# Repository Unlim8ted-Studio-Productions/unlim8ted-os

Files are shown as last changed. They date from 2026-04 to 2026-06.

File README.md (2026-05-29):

<div align="center">
<h1>Unlim8ted Phone</h1><p>A custom CM4-based handheld phone project</p>

<br>





<table>
<tr>

<td width="50%">
  <a href="https://raw.githubusercontent.com/Unlim8ted-Studio-Productions/unlim8ted-phone/refs/heads/main/docs/assets/render.mkv">
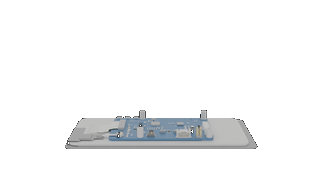
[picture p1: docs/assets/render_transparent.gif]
  
</a>
</td>

<td width="50%">
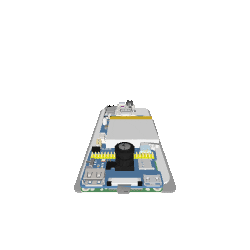
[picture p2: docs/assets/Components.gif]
  
</td>

</tr>
</table>

</div>

---

<h2>Overview</h2>

<p>
Unlim8ted Phone is a handheld phone project built around the Raspberry Pi Compute Module 4.
</p>

<p>
This repository contains the hardware, enclosure design, operating system work, and archived PCB development files for the project.
</p>

---

<h2>Repository Layout</h2>

```text
/
├─ 3d/        enclosure, renders, printable parts
├─ docs/      project documentation
├─ os/        Unlim8ted OS source and docs
├─ pcb/       archived PCB design files
└─ README.md
```

---

<h2>Hardware + Cost Breakdown</h2>

<table>

<tr>
<th align="left">Component</th>
<th align="left">Details</th>
<th align="right">Price</th>
</tr>

<tr>
<td>Compute Module</td>
<td>Raspberry Pi CM4 Lite — 8GB RAM</td>
<td align="right">$105.00</td>
</tr>

<tr>
<td>Carrier Board</td>
<td>Waveshare CM4-NANO-C</td>
<td align="right">$29.99</td>
</tr>

<tr>
<td>Display</td>
<td>Waveshare 6.25-inch DSI LCD</td>
<td align="right">$59.99</td>
</tr>

<tr>
<td>Storage</td>
<td>32GB microSD card</td>
<td align="right">$20.00</td>
</tr>

<tr>
<td>Power Board</td>
<td>Seeed LiPo Rider Plus</td>
<td align="right">$4.90</td>
</tr>

<tr>
<td>Battery</td>
<td>3.7V 3000mAh LiPo</td>
<td align="right">$12.49</td>
</tr>

<tr>
<td>Display Cable</td>
<td>15cm double-sided 15-pin DSI cable</td>
<td align="right">Included</td>
</tr>

<tr>
<td>USB Cable</td>
<td>Adafruit USB Type A → USB Type C</td>
<td align="right">$2.95</td>
</tr>

</table>

<br>

<div align="center">

<h1>$235.32</h1>

<sub>Current estimated build total</sub>

</div>

---

<h2>PCB Status</h2>

<p>
The PCB files inside <code>/pcb</code> are archived only.
</p>

<p>
The original custom PCB revision was abandoned in favor of already-manufactured off-the-shelf boards.
</p>

<p>
These files are preserved strictly for reference purposes and should not be used for fabrication or assembly.
</p>

---

<h2>Project Links</h2>

<div align="center">

<a href="./docs/">Documentation</a>

<br><br>

<a href="./os/">OS Source</a>

<br><br>

<a href="./3d/">3D Files</a>

<br><br>

<a href="./pcb/">Archived PCB Files</a>

</div>

---

<div align="center">

<h3>Unlim8ted Studios</h3>

<p>
Hardware • Embedded Systems • OS Development • Industrial Design
</p>

</div>

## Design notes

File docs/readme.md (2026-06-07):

# Unlim8ted Phone Docs

This folder documents the Unlim8ted Phone repository as it exists today: the CM4 software stack, enclosure assets, hardware baseline, and archived board work.

## What is in this repo

- A Raspberry Pi CM4 kiosk-style phone shell and backend under `os/`
- Printable enclosure exports and supporting 3D assets under `3d/`
- Archived custom PCB work under `pcb/`
- Project-level notes in this `docs/` folder

## Start here

- [Repository Map](repo-map.md)
- [OS Architecture](os-architecture.md)
- [Hardware And Design Notes](hardware-and-design.md)

## Current direction

The project is currently built around off-the-shelf CM4 hardware, a custom enclosure, and a custom kiosk-style software stack.

The `pcb/` tree remains useful reference material, but it is no longer the active hardware path.

## Important repo realities

- The main software entrypoint is `os/build.sh`, which now only handles the deferred CM4 flash-and-first-boot flow rather than acting as a general image builder.
- The device UI is a local web app served by a Python backend on port `8080`.
- The app set is mostly local-first and stateful, with several apps backed by JSON files under the runtime state directory.
- Some Blender source may live outside the pushed repository; the tracked tree primarily preserves exports and reference assets.

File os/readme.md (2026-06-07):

# Unlim8ted OS

This directory now builds Unlim8ted OS by customizing official upstream Linux images instead of compiling a full Buildroot system from source.

## Structure

- `overlay/` holds the files copied into the target image, including `/etc`, `/opt`, and the Raspberry Pi boot configuration tracked in this repo.
- `build.sh` is the main build entrypoint for the deferred CM4 provisioning flow.
- `reapply-overlay.sh` reapplies the current overlay to an existing CM4 card without reflashing the base image.
- `build/` receives the finished artifacts after each build.

## Base Images

- CM4 now defaults to the official Raspberry Pi OS Lite 64-bit image `2026-04-21-raspios-trixie-arm64-lite.img.xz`. This is the April 21, 2026 Raspberry Pi OS Lite release for Raspberry Pi 4 / CM4 class hardware.
- `x86_64` uses the official Debian 12 amd64 generic cloud image. That keeps Chromium available as a normal apt package and is straightforward to boot under QEMU or other desktop virtualization.

## Included software

Both targets install kiosk-oriented packages with `apt`, then apply the repo overlay:

- `systemd` from the base image
- `python3`
- `Chromium`
- Bluetooth support
- Wi-Fi support
- Xorg and `xinit`
- `openbox`

The overlay still provides the kiosk startup path:

- `etc/systemd/system/getty@tty1.service.d/autologin.conf` skips the tty1 login prompt.
- `etc/systemd/system/unlim8ted.service` starts X with `xinit`.
- `opt/unlim8ted/bin/kiosk-session.sh` starts the backend, and the backend launches Chromium in app mode.

## Requirements

Run `build.sh` from a Linux shell, including WSL.

Required host tools:

- `sudo`
- `curl`
- `losetup`
- `mount`
- `parted`
- `resize2fs`
- `e2fsck`
- `rsync`
- `unzip`
- `xz-utils`

Additional requirement for CM4 DSI1 boot overlay generation:

- `p7zip-full`
- `device-tree-compiler`

Additional requirement when building the default CM4 image on an `x86_64` host:

- `qemu-arm-static`

The build script flashes the base image, resizes partitions, applies the overlay, seeds first-boot settings, and enables the first-boot installer.

## CM4 Card Layout

Default Unlim8ted card partitions:

- `3 - storage ext4` is the user storage partition for files, downloads, pictures, videos, music, and captures.
- `2 - rootfs ext4` is the OS filesystem with `/opt/unlim8ted`.
- `1 - bootfs FAT` is the Raspberry Pi boot partition.

The boot files must be on the real FAT `bootfs` partition. An empty `rootfs\boot\firmware` directory is normal when `bootfs` is not mounted there.

For the Waveshare DSI1 + double-camera CM4 setup, `build.sh` can optionally install `dt-blob.bin` into `bootfs`. By default it builds that file from Waveshare's `dt-blob-disp1-double_cam.dts`, which can affect camera and HDMI behavior. The build script does not copy `.dts` files into `bootfs`; set `UNLIM8TED_CM4_DSI1_DT_BLOB=1` to enable `dt-blob.bin` generation, or place a prebuilt `overlay/boot/dt-blob.bin` in the repo to override the generated path.

The tracked boot overlay also forces `dtoverlay=dwc2,dr_mode=host` so USB input devices enumerate in host mode during CM4 testing.

## Build Script

Common commands:

```sh
# Show disks before selecting a target.
bash os/build.sh list-devices

# Deferred CM4 build: flash the pinned stock OS, resize rootfs, apply overlay, install packages on first boot.
bash os/build.sh deferred --device /dev/sdi

# Override the deferred CM4 rootfs target size.
bash os/build.sh deferred --device /dev/sdi --root-size-mib 9728

# Seed first-boot Wi-Fi credentials during a deferred build.
bash os/build.sh deferred --device /dev/sdi --wifi-ssid "MyWiFi" --wifi-password "secret" --wifi-country US

# Reapply the current overlay to an already-flashed CM4 card.
sh os/reapply-overlay.sh /dev/sdi
```

Deferred CM4 builds flash the pinned stock Raspberry Pi OS Lite image directly to the selected device, expand `rootfs` to 10GiB by default, create `LABEL=storage` from the remaining space, apply the overlay, and skip host-side package installation. If the build is running interactively, the script asks for the Wi-Fi country first, defaulting to `US`, then optionally asks for an SSID/password and writes those settings into the first-boot environment file.

On first boot:

- the image autologins root on `tty1`
- `firstboot-install.sh` waits indefinitely for network input if needed
- package installation runs on the CM4
- on success, `unlim8ted.service` starts the kiosk
- on failure, the script drops into an interactive recovery shell on `tty1`

If you land in the recovery shell and the system is otherwise ready, you may only need to type `reboot`.

Default credentials seeded into the image:

- username: `unlim8ted`
- password: `unlim8ted`

The `storage` partition is mounted at `/home/unlim8ted` and is used for user files, downloads, pictures, videos, music, and captures.

Optional environment variables:

- `UNLIM8TED_WORK_DIR=...` sets the build work/cache directory.
- `UNLIM8TED_BASE_IMAGE_DIR=...` sets the base image cache directory.
- `UNLIM8TED_CM4_PACKAGES=...` overrides the apt package list for CM4.
- `UNLIM8TED_DEFAULT_USER=...` overrides the seeded default username.
- `UNLIM8TED_DEFAULT_PASSWORD=...` overrides the seeded default password.

## Notes

- The build is now much faster than a full Buildroot desktop stack because it reuses prebuilt distro packages.
- You still keep the repo-managed overlay and boot config.

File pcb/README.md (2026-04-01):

# PCB Folder

This folder contains outdated and unfinished PCB design work, archived revisions, fabrication output, supporting libraries, and reference material for the phone project. None of the custom PCB files should be fabricated, and ignoring this warning could result in damage.

## Layout

- `custom pcb files/`
  - the KiCad project folders and board files
  - currently includes `phone/`, `phone-part-1/`, and `phone6layer/`
- `libraries/`
  - custom symbol and footprint libraries
  - vendor library imports used by the projects
- `models/`
  - component, enclosure, and vendor-supplied 3D assets
- `fabrication/`
  - gerbers, pick-and-place files, plots, and JLCPCB exports
- `references/`
  - datasheets, diagrams, screenshots, and video captures
- `scripts/`
  - helper scripts used alongside the PCB workflow
- `archives/`
  - backups, candidate revisions, zip bundles, and superseded files

## Working Projects

- `custom pcb files/phone/`
  - main phone schematic project and its exported 3D artifacts
- `custom pcb files/phone6layer/`
  - 6-layer phone board revision
- `custom pcb files/phone-part-1/`
  - partial board split-out

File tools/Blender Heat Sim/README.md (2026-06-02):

# CAD Heat Sim Blender Add-on

Install the `Blender Heat Sim` folder as a Blender add-on zip or copy it into your Blender add-ons directory.

What it does:
- Adds a `Heat Sim` tab to the 3D View sidebar.
- Lets you assign thermal material presets or custom thermal properties per object.
- Simulates transient heating with internal power, fixed-temperature boundaries, object-to-object contact conduction, convection, and radiation.
- Supports component presets with idle-to-max power scaling driven by a scene-wide load control.
- Colors the model by temperature and exports summary CSV data.
- Includes improved preview controls for current-frame contrast, hottest/coolest part readout, and one-click viewport setup.
- Uses a two-node core/surface thermal model per object for better internal-vs-external temperature behavior.
- Uses adaptive predictor-corrector time integration and face-aware contact estimation for higher numerical and geometric fidelity.
- Supports a free `SfePy` server backend that voxelizes the Blender scene and solves a transient thermal FEM case in an external Python environment.

Included presets:
- Metals and structural materials such as aluminum, copper, stainless steel, titanium, glass, silicon, graphite pad, and PCB FR4.
- Printed and enclosure materials such as ABS, PLA, polycarbonate, TPU, and nylon.
- Electronics-oriented presets such as `LiPo Battery`, `CM4 PCB`, `CM4 SoC Package`, `CM4 Module`, and `Waveshare 6.25 DSI Display`.
- Assembly and interface materials such as `Steel Screw`, `Brass`, `Ceramic`, `Thermal Pad`, `Thermal Paste`, `FPC Ribbon Cable`, and `Adhesive Tape`.
- Device presets for `Raspberry Pi CM4 Lite 8GB`, `Waveshare CM4-NANO-C`, `Waveshare 6.25-inch DSI LCD`, `32GB microSD Card`, `Seeed LiPo Rider Plus`, `3.7V 3000mAh LiPo`, `15cm 15-pin DSI Cable`, and `USB Type A to Type C Cable`.

Recommended workflow:
1. Import or model your CAD parts as separate mesh objects with real-world scale in meters.
2. Select an object, choose a component preset when appropriate, and sync it to copy material and power defaults.
3. Set the scene `System Load` slider to represent idle through maximum sustained use.
4. Use load profiles for active components such as compute modules, displays, chargers, and batteries, or manual heat generation for custom parts.
5. Select objects and apply material or component presets to the rest of the assembly as needed.
6. Mark heatsinks, cold plates, or environment-controlled parts as fixed-temperature boundaries when needed.
7. Run the simulation and inspect the final frame or scrub the preview frame slider.

SfePy workflow:
1. In add-on preferences, set `Server Python` to a normal Python installation outside Blender.
2. Use `Install Server Modules` to install `numpy`, `scipy`, `sfepy`, `trimesh`, and `numpy-stl` into that external Python environment.
3. Use `Start Solver Server` once, or keep `Auto Start Server` enabled.
4. In the Heat Sim panel, switch `Backend` to `SfePy Server`.
5. Set `SfePy Cell Size` small enough for the geometry detail you care about.
6. Use `Export SfePy Case` to generate the voxel mesh and solver files, or `Run SfePy Server Solve` to solve through the server.
7. The add-on writes the generated case, compressed voxel mesh data, Python runner, and server log into the configured case folder.

Mesh viewer:
- Use `tools/Blender Heat Sim/mesh_viewer.py` to inspect generated `.mesh` files outside Blender.
- Example:
```powershell
python "O:\unlim8ted-phone\tools\Blender Heat Sim\mesh_viewer.py" "O:\unlim8ted-phone\3d\heat_sim_cases\heat_sim_full_sfepy\heat_sim_full.mesh"
```
- If no path is provided, the viewer opens a file picker.

Preview tips:
- Use `Set Preview View` to switch Blender to a heat-map friendly material preview automatically.
- Use `Color Scope = Whole Run` to compare temperatures across the entire simulation.
- Use `Color Scope = Current Frame` for stronger contrast at the selected preview time.
- Use `Color Scope = Manual` when you want a fixed engineering temperature scale.
- Use `Preview Temp = Surface`, `Core`, or `Max` depending on whether you want touch temperature, internal hotspot temperature, or the worst-case of both.
- Read the `Hot` and `Cool` labels in the preview panel to see the extreme parts at the current frame quickly.

Accuracy notes:
- Keep geometry to real-world scale in meters.
- Lower `Max Temp Step` for higher temporal accuracy at the cost of longer solve time.
- Lower `SfePy Cell Size` for higher spatial fidelity in the SfePy backend.
- Use separate objects for heat sources, boards, pads, shields, batteries, and displays instead of one merged assembly.
- Use manual thickness overrides on thin stacked parts when the automatic estimate is too coarse.

Notes:
- This is a materially aware lumped thermal network solver inside Blender. It is useful for design iteration, comparison, and finding hot spots.
- It is not a substitute for full finite-element thermal analysis when you need certification-grade accuracy or detailed internal gradients inside a single part.

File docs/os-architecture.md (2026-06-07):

# OS Architecture

## Overview

Unlim8ted OS in this repository is an image-customization workflow rather than a full distribution source tree. It starts from upstream base images, installs the required packages, applies the repo overlay, and enables the kiosk runtime.

There is one supported target:

- `cm4`: Raspberry Pi OS Lite 64-bit based image for the device

## Boot and runtime flow

At runtime the system follows this boot chain:

1. `unlim8ted.service` starts `xinit` on `tty1`
2. `kiosk-session.sh` disables screen blanking, starts Openbox, and launches the backend
3. `backend/main.py` starts a local HTTP server on port `8080`
4. The same Python process launches Chromium in app/kiosk mode pointed at `http://localhost:8080`
5. Chromium loads `ui/index.html` and `ui/app.js`
6. The shell opens apps by calling backend routes, which dispatch into `apps/<app>/main.py`

## Backend responsibilities

`os/overlay/opt/unlim8ted/backend/main.py` is the main runtime process. It is responsible for:

- Serving the shell HTML and JavaScript
- Serving app templates and client scripts
- Routing app API requests
- Sleep, wake, brightness, reboot, shutdown, and kiosk-exit actions
- Wi-Fi and Bluetooth toggles
- Companion pairing/session endpoints
- Media file serving for captures
- Chromium launch

## Runtime services

`os/overlay/opt/unlim8ted/backend/runtime.py` provides the local service layer used by apps.

Key services:

- `StateStore`: JSON-backed persistence under the runtime state directory
- `ContactsService`: default/favorite contacts
- `CommunicationsService`: calls, threads, and messages
- `AccountsService`: owner and mail account state
- `MediaService`: captures and music queue state
- `FilesService`: sandboxed access to allowed filesystem roots
- `NotificationsService`: badge counts and notification state
- `CompanionService`: pairing codes, sessions, device list, and push token metadata
- `AppRegistry`: app discovery and dynamic loading from `apps/*/main.py`

## UI shell

The shell is a mobile-style single-page interface implemented in `ui/index.html` and `ui/app.js`.

Key shell behavior visible in the current implementation:

- Lock screen and home screen flow
- Control center and quick toggles
- Sleep/wake behavior with idle timeout
- App switcher
- Soft keyboard with suggestions and glide typing
- Home screen page swiping and icon rearrangement
- Lightweight performance mode detection for ARM/Linux targets
- Error isolation so a failed app does not kill the shell

## App model

Apps are local modules under `os/overlay/opt/unlim8ted/apps/<app-id>/`.

Common parts:

- `main.py`: manifest plus server-side payload/action logic
- `index.html`: optional app template
- `client.js`: optional rich client behavior

The backend loads app manifests dynamically. Some apps return structured payloads for generic rendering, while others ship dedicated templates and client-side behavior.

## Data and storage

Default runtime paths are configured in `overlay/etc/default/unlim8ted`:

- state: `/var/lib/unlim8ted`
- user storage: `/home/unlim8ted`
- user files: `/home/unlim8ted/Files`
- captures: `/home/unlim8ted/Pictures/Captures`
- Chromium profile: `/var/lib/unlim8ted/chromium-profile`

The CM4 image layout also reserves a separate `storage` partition mounted at `/home/unlim8ted`.

## Build workflow summary

`os/build.sh` now supports one provisioning flow only:

- flash the pinned Raspberry Pi OS Lite base image to an SD or USB device
- resize the root partition to a fixed size
- create a `storage` partition for `/home/unlim8ted`
- apply the tracked overlay
- suppress Raspberry Pi OS first-run setup
- boot into `tty1` root autologin
- run `firstboot-install.sh` on the device after network is available

The deferred first-boot script installs packages on the target device instead of preinstalling them during image creation.

Current first-boot behavior:

- `tty1` autologins root
- `firstboot-install.sh` prompts for network access if needed and waits indefinitely
- on failure, the script opens an interactive recovery shell on `tty1`
- if the system is otherwise ready, a simple `reboot` may be enough to continue cleanly on the next boot

The image also seeds a default local user for Raspberry Pi OS first-run setup suppression:

- username: `unlim8ted`
- password: `unlim8ted`

## Practical caveats

- The build script must run from Linux or WSL, not native Windows.
- Several apps are intentionally local-state implementations rather than fully integrated phone services.
- Package installation now happens on first boot, so network availability on the device is part of provisioning.

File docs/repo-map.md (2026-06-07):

# Repository Map

## Top level

- `README.md`: project overview and current hardware cost summary
- `docs/`: repo documentation
- `os/`: Unlim8ted OS image builder, overlay, backend, UI, and bundled apps
- `3d/`: enclosure exports, renders, and model assets
- `pcb/`: archived KiCad projects, fabrication output, vendor libraries, and references

## `os/`

This is the active software side of the project.

- `build.sh`: single-purpose CM4 deferred flasher that writes the base image, applies the overlay, and leaves package installation to first boot on the device
- `overlay/boot/config.txt`: tracked Raspberry Pi boot configuration for the Waveshare DSI panel and camera setup
- `overlay/etc/default/unlim8ted`: runtime environment variables for display, storage, captures, and Chromium profile paths
- `overlay/etc/systemd/system/unlim8ted.service`: kiosk systemd service that launches `xinit`
- `overlay/opt/unlim8ted/bin/kiosk-session.sh`: starts Openbox and then the Python backend
- `overlay/opt/unlim8ted/backend/`: Python backend and runtime services
- `overlay/opt/unlim8ted/ui/`: phone shell HTML and JavaScript
- `overlay/opt/unlim8ted/apps/`: per-app templates, Python logic, and optional client scripts
- `overlay/opt/unlim8ted/commands/registry.json`: command surface exposed to the shell and companion-facing clients

## `os/overlay/opt/unlim8ted/apps/`

Current app folders discovered from the repo:

- `browser`: local tab state and embedded browser shell
- `camera`: camera actions and capture flow
- `clock`: alarms, timers, and world clock state
- `code`: text/code editor over the user files area
- `files`: file browser, preview, editing, rename, and delete operations
- `gallery`: capture browser
- `mail`: local mailbox and draft state
- `maps`: placeholder destination/search state
- `messages`: local conversation state plus companion sync support
- `music`: local queue and playback state
- `notes`: local notes state
- `phone`: favorites, dial, contacts, and recents
- `settings`: account, system, notification, and connectivity summary
- `store`: installed app list and command surface view
- `terminal`: terminal app frontend/backend

Several of these apps are local-first modules backed by JSON state rather than external service integrations.

## `3d/`

This tree contains printable and presentation assets for the enclosure side of the project.

- Exported printable parts such as `Back_Cover.stl`, `Bottom_Cover.stl`, `Battery_Holder.stl`, and `Main_Case.stl`
- Render outputs such as `render.gif`, `render.mkv`, and `Components.gif`
- Mixed source/reference assets including `.glb` and `.stl` files.

## `pcb/`

This tree is archived.

- `custom pcb files/`: primary KiCad project folders and board revisions
- `libraries/`: imported or custom footprints/symbols
- `models/`: vendor and reference 3D assets
- `fabrication/`: gerbers and fabrication exports
- `references/`: screenshots, diagrams, schematics, datasheets, and videos
- `scripts/`: helper tooling such as the KiCad-to-OpenSCAD case generator
- `archives/`: backups, candidate layouts, zips, and superseded revisions

## `docs/assets`

Various renders used in the documentation.

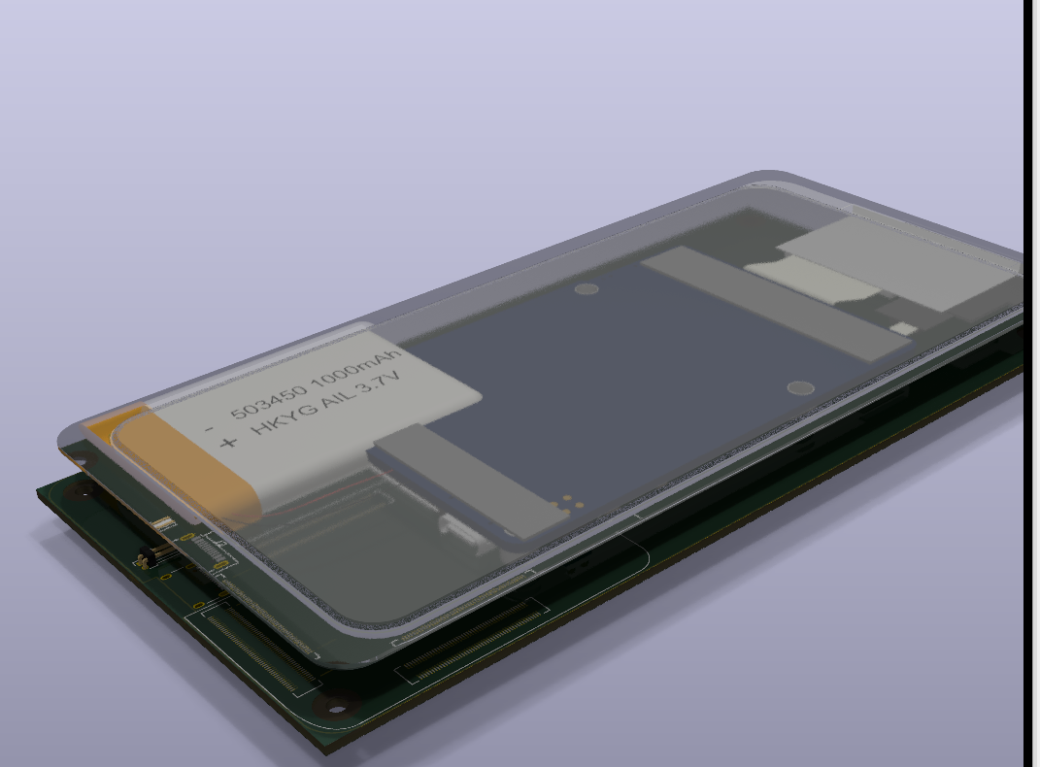
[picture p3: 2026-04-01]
pcb/references/images/Screenshot 2025-11-21 183611.png

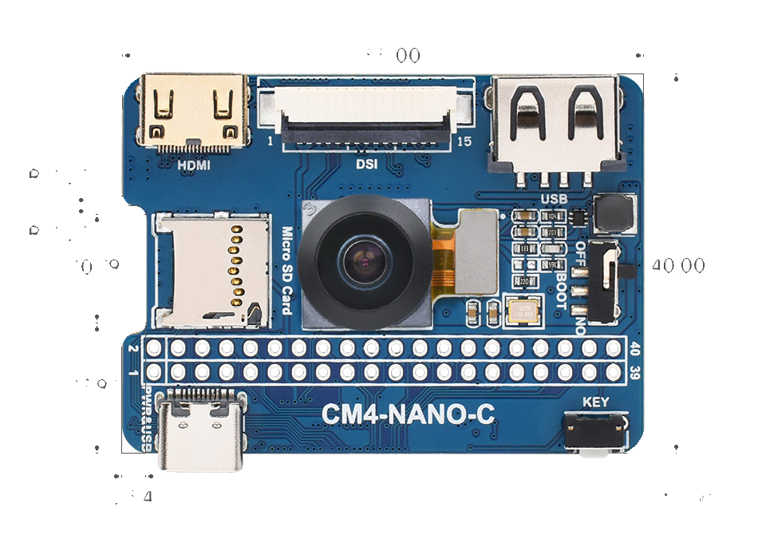
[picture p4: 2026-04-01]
pcb/references/images/PineTools.com_CM4-NANO-C02.png

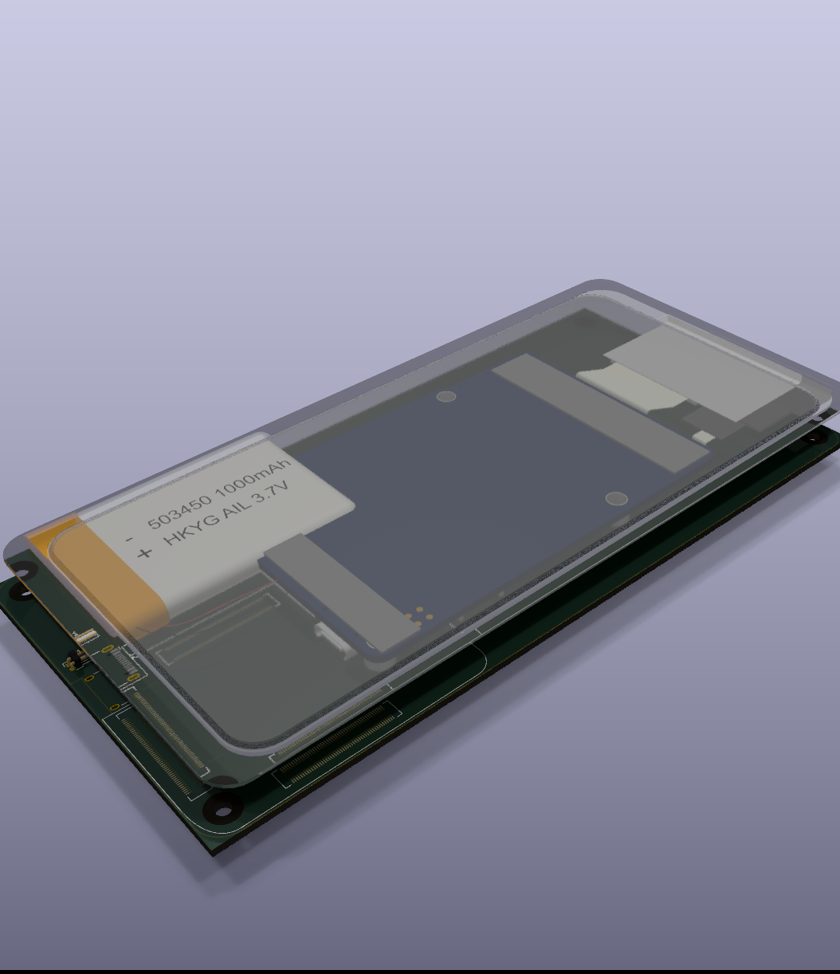
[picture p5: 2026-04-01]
pcb/references/images/Screenshot 2025-11-21 183740.png

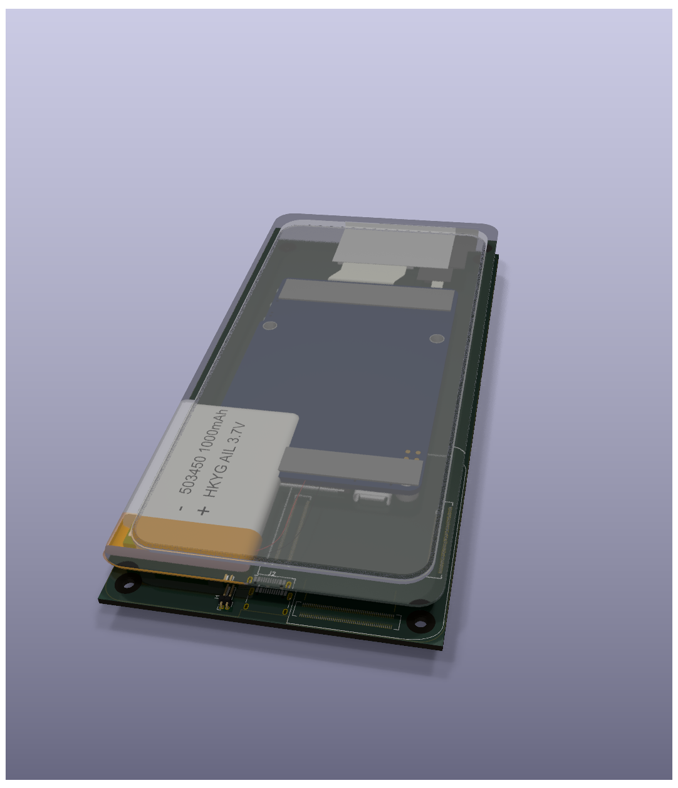
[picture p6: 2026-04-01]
pcb/references/images/Phone.png

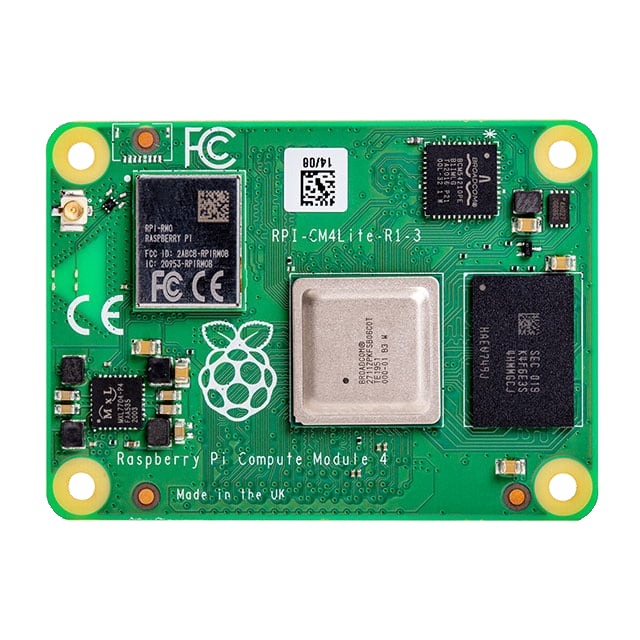
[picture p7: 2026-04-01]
pcb/references/images/PineTools.com_MFG_CM4-Lite.png

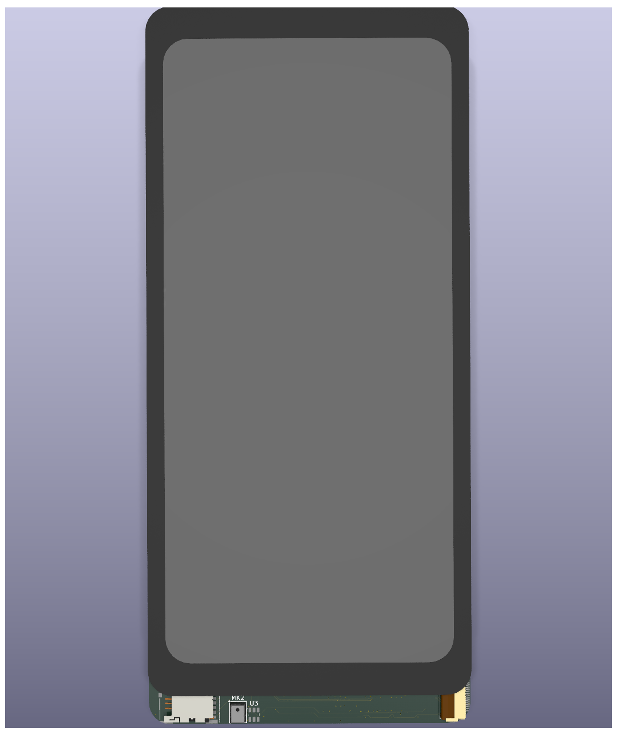
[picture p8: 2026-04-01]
pcb/references/images/PhonefinishedV1side2.png

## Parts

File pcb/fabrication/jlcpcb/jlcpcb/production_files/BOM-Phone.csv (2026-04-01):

Comment | Designator | Footprint | LCSC | Quantity
L | L1 | L_0201_0603Metric |  | 1
110 kΩ | R_top1 | R_0201_0603Metric |  | 1
Conn_01x04_Pin | J2 | PinHeader_1x02_P1.00mm_Horizontal |  | 1
nf | R17 | R_0402_1005Metric |  | 1
nf | R18 | R_0402_1005Metric |  | 1
Conn_01x02 | J8 | JST_PH_S2B-PH-K_1x02_P2.00mm_Horizontal |  | 1
BQ24074RGT | U2 | VQFN-16-1EP_3x3mm_P0.5mm_EP1.6x1.6mm |  | 1
12K 1% | R29 | R_0402_1005Metric |  | 1
Conn_01x05_Pin | J6 | PinHeader_1x05_P1.00mm_Horizontal |  | 1
22 µF | R5 | R_0201_0603Metric |  | 1
D | D2 | D_0201_0603Metric |  | 1
Conn_01x22_Female | J4 | Hirose_FH12-22S-0.5SH_1x22-1MP_P0.50mm_Horizontal |  | 1
Conn_01x22_Female | J15 | Hirose_FH12-22S-0.5SH_1x22-1MP_P0.50mm_Horizontal |  | 1
0.1 µF | C3 | C_0201_0603Metric |  | 1
MT3608 | U5 | SOT-23-6 |  | 1
RT9742GGJ5 | U18 | SOT-23-5 |  | 1
2.2 nF | C2 | C_0201_0603Metric |  | 1
22 µF | R7 | R_0201_0603Metric |  | 1
10u | C5 | C_0805_2012Metric |  | 1
MPU-9150 | U4 | InvenSense_QFN-24_4x4mm_P0.5mm |  | 1
ComputeModule4 | U1 | Raspberry-Pi-4-Compute-Module-Connector-Phone-Modified |  | 1
APDS-9301 | U3 | Broadcom_APDS-9301 |  | 1
Conn_01x22_Female | J5 | Hirose_FH12-22S-0.5SH_1x22-1MP_P0.50mm_Horizontal |  | 1
Micro_SD_Card_Det | J7 | SDCARD_MOLEX_503398-1892 |  | 1
MP45DT02 | MK2 | ST_HLGA-6_3.76x4.72mm_P1.65mm |  | 1
DF40C-100DS | U1A | e30f3db5-79c3-4296-a91e-8cada387ac0b |  | 1
DF40C-100DS | U1B | 81a00ac8-e87d-4e7e-8d85-8e0ea2ee5095 |  | 1

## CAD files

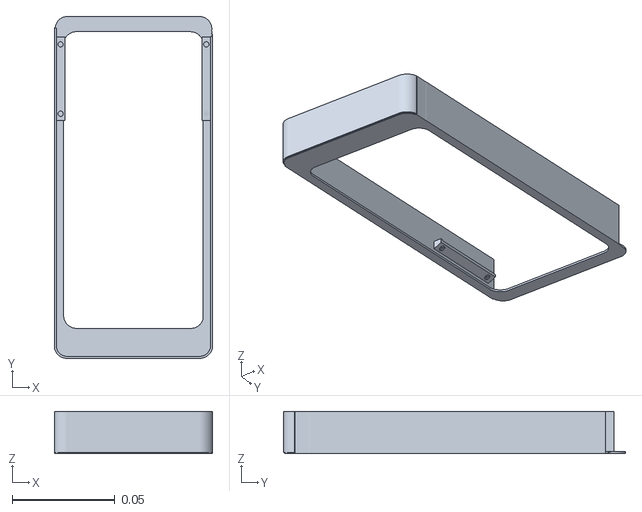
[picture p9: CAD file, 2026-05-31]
3d/STL/Main_Case.stl
0.0771 x 0.166 x 0.0206

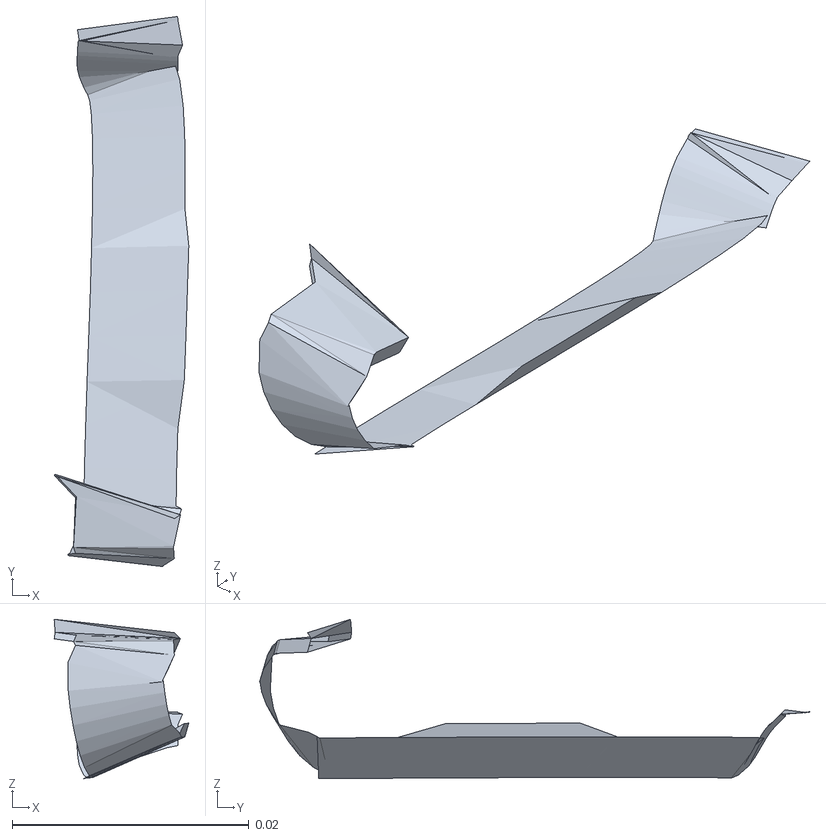
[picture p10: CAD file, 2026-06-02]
3d/heat_sim_cases/heat_sim_full_sfepy/meshes/dsi_cable.stl
0.0114 x 0.0465 x 0.0135

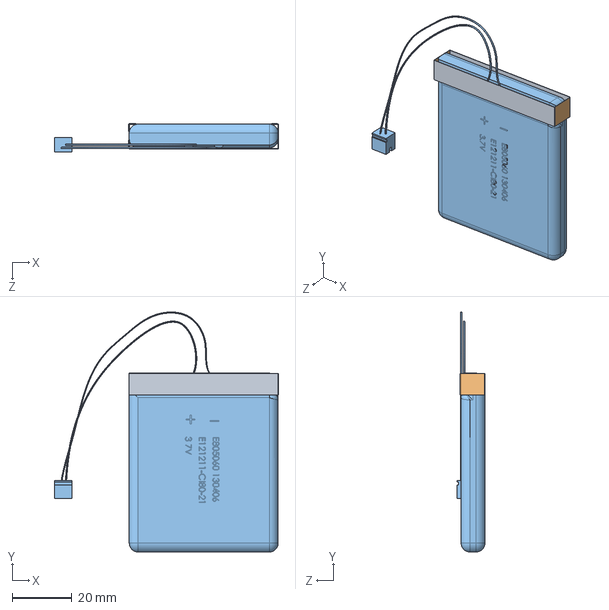
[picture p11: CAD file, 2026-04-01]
pcb/models/components/Battery 2500mAh.STEP
75.2 x 80.5 x 9.55 mm

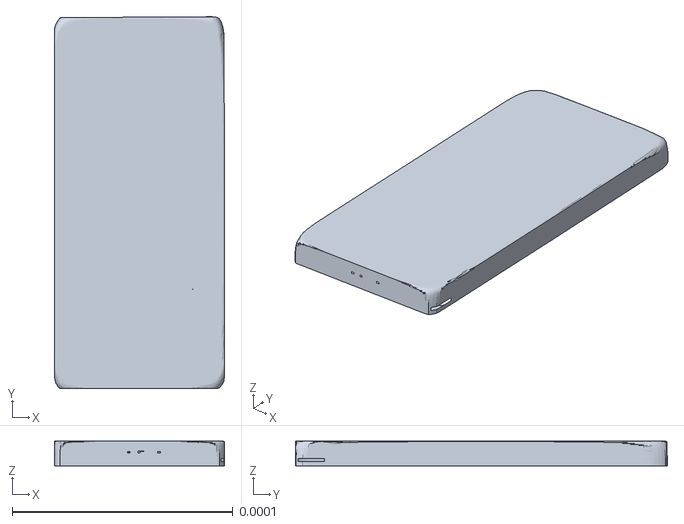
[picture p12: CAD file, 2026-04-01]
pcb/models/enclosure/phone_case_for_printV2.stl
7.71e-05 x 0.000168 x 1.13e-05

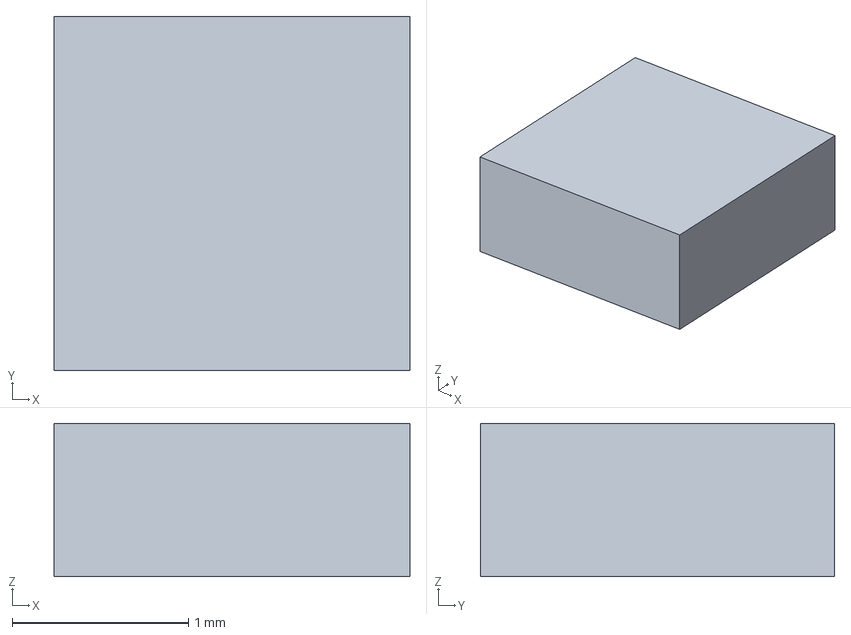
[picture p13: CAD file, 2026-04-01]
pcb/references/pcb/measurement-1mm/1mmmeasurement.step
2.02 x 2.01 x 0.869 mm

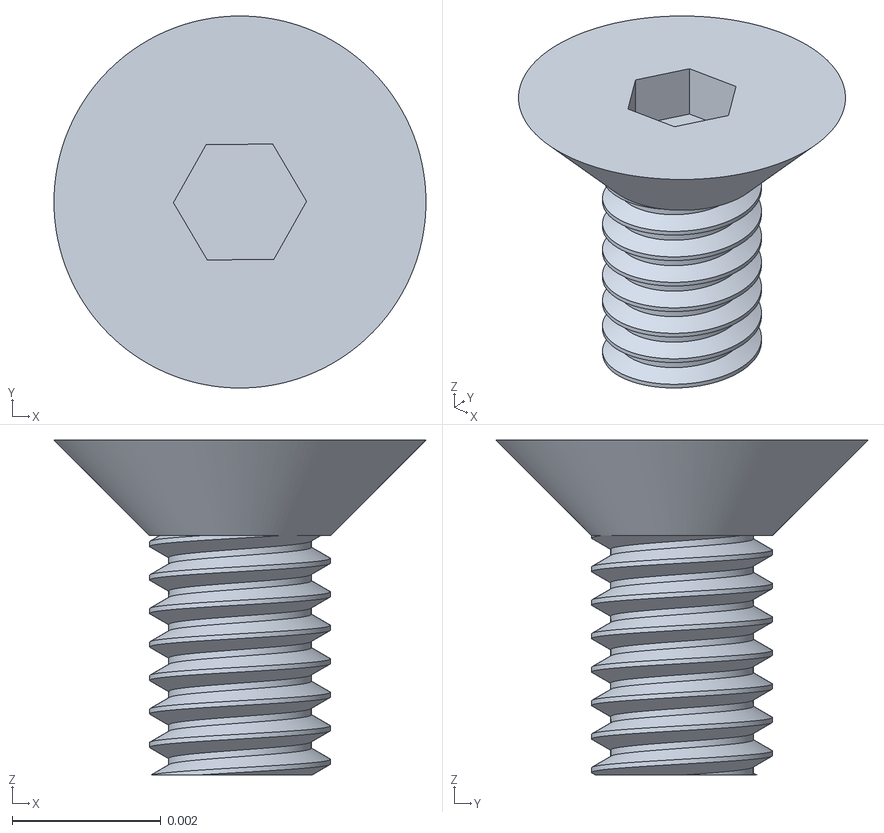
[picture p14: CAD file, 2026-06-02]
3d/heat_sim_cases/heat_sim_full_sfepy/meshes/part22_3mm_001.stl
0.005 x 0.005 x 0.0045

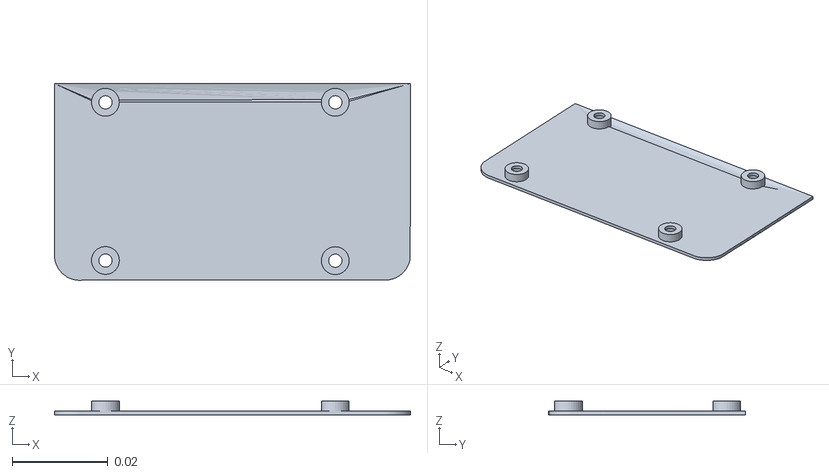
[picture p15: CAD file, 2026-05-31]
3d/STL/Compute Module Plane.stl
0.0743 x 0.041 x 0.00285

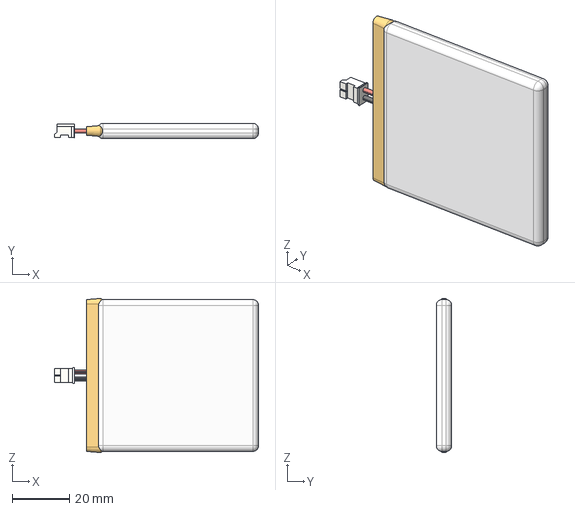
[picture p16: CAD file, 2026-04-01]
pcb/models/components/LiPo Battery v5.step
71.2 x 5.38 x 53.8 mm

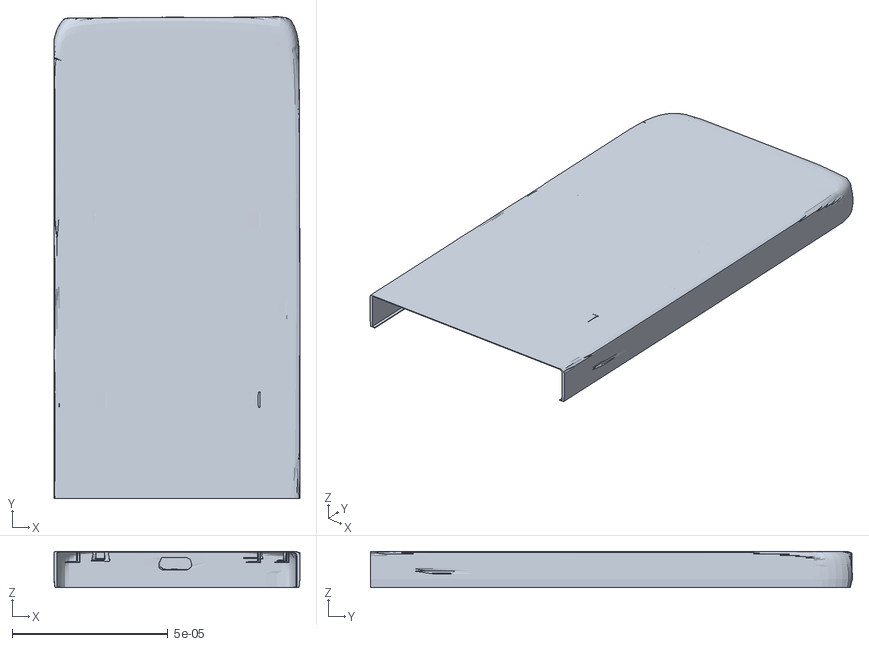
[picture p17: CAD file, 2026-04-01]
pcb/models/enclosure/model_case5.stl
7.9e-05 x 0.000155 x 1.17e-05

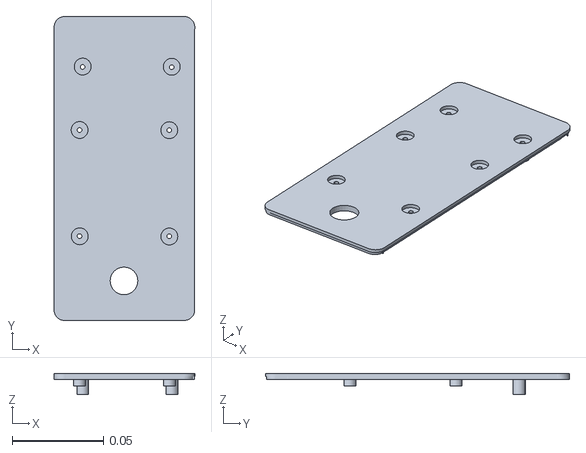
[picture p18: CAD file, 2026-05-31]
3d/STL/Back_Cover.stl
0.0769 x 0.166 x 0.0116

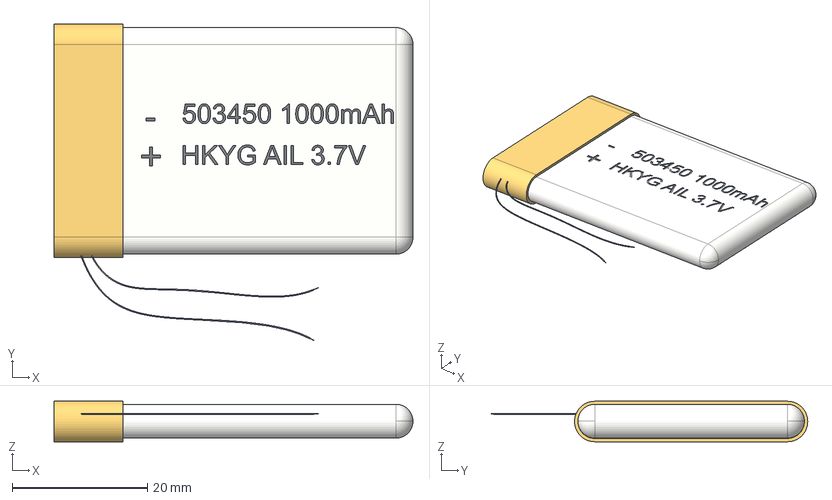
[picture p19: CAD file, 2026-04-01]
pcb/models/components/Bateria LiPo 3.7V 1000mA 503450 v23.step
53.1 x 46.8 x 6.00 mm

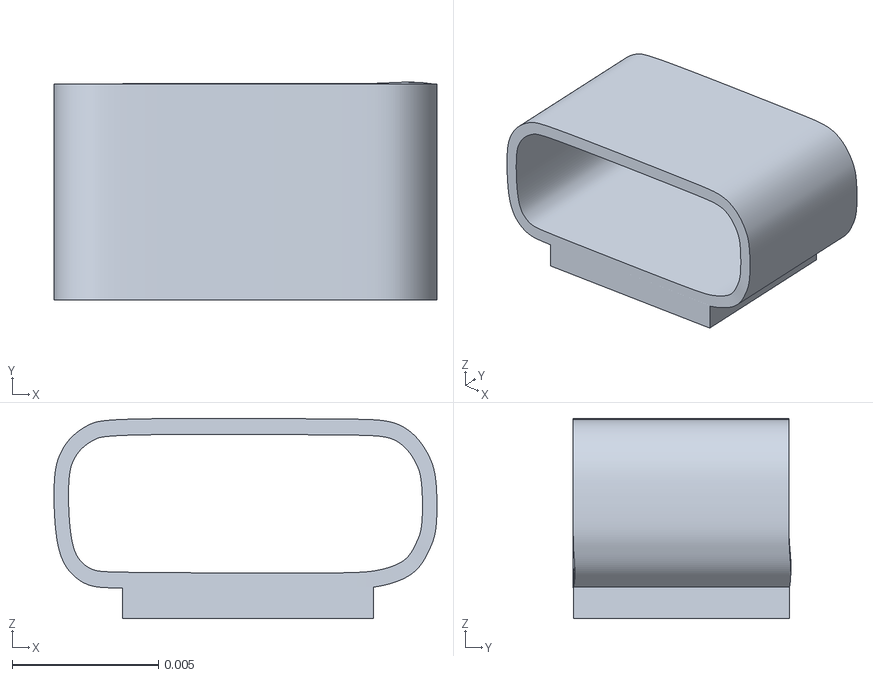
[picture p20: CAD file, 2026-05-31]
3d/STL/Type_C_Port_Entrance.stl
0.0131 x 0.00744 x 0.00685

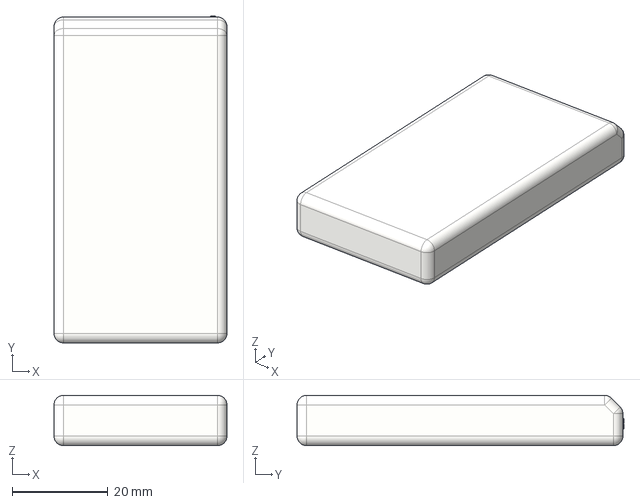
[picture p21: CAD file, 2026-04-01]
pcb/models/components/3000mah battery v4.step
36.1 x 68.2 x 10.5 mm

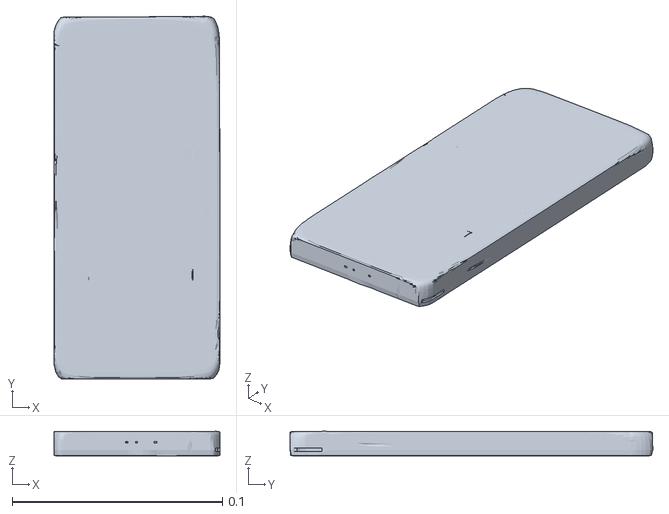
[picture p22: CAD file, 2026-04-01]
pcb/models/enclosure/phone_case_for_printV1_fixed.stl
0.079 x 0.173 x 0.0117

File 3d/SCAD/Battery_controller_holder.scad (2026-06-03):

// ============================================================
// Battery_Controller_Holder.scad
//
// Flat controller mounting plate that slides onto the Main_Case
// overhang and fits against the Bottom_Cover.
//
// Corrected:
//   - Includes all 10 visible through holes
//
// Units: mm
// ============================================================

$fn = 96;

// ============================================================
// OVERALL PLATE DIMENSIONS
// ============================================================

plate_w = 75.77920;
plate_d = 49.61260;
plate_t = 1.25191;

// Rounded corners on the upper side.
// Lower side remains square as in the previous version.
top_corner_r = 6.0;

// ============================================================
// THROUGH HOLES
// ============================================================

hole_d = 2.58313;

// Optional extra clearance for printing
hole_clearance = 0.0;

final_hole_d = hole_d + hole_clearance;

// ============================================================
// HOLE LOCATIONS
// ============================================================
//
// Orientation:
//
//              ROUNDED / TOP SIDE
//
//       o          o       o          o
//
//              o                   o
//
//       o          o       o          o
//
//              SQUARE / BOTTOM SIDE
//
// X = left/right across wide plate
// Y = bottom/top along short plate depth
//
// Positions are centered relative to the plate.
// ============================================================

hole_positions = [

    // Far-left outer column
    [-35.4335,  11.2380],     // upper-left outer
    [-35.4335, -22.5160],     // lower-left outer   ADDED

    // Left-middle hole
    [-22.7505,  -2.8060],

    // Inner upper pair
    [ -5.8955,   6.5120],
    [ 14.6195,   6.5120],

    // Inner lower pair
    [ -5.6835, -21.0880],
    [ 14.6195, -21.0880],

    // Right-middle hole
    [ 25.8846,  -2.8060],     // ADDED

    // Far-right outer column
    [ 35.4375,  11.2380],     // upper-right outer
    [ 35.4375, -22.5160]      // lower-right outer
];

// ============================================================
// OPTIONAL PREVIEW SETTINGS
// ============================================================

// Set true to show the edge expected to sit against Bottom_Cover.
show_bottom_cover_edge_reference = false;

// Set true to show hole centers above the plate in preview.
show_hole_reference_posts = false;

// ============================================================
// PLATE PROFILE
// ============================================================
//
// Produces:
//   - square lower-left corner
//   - square lower-right corner
//   - rounded upper-left corner
//   - rounded upper-right corner
// ============================================================

module controller_plate_profile_2d() {

    union() {

        // Full-width lower rectangular body
        translate([
            -plate_w / 2,
            -plate_d / 2
        ])
            square([
                plate_w,
                plate_d - top_corner_r
            ]);

        // Central section extending to upper edge
        translate([
            -plate_w / 2 + top_corner_r,
            -plate_d / 2
        ])
            square([
                plate_w - top_corner_r * 2,
                plate_d
            ]);

        // Upper-left rounded corner
        translate([
            -plate_w / 2 + top_corner_r,
             plate_d / 2 - top_corner_r
        ])
            circle(r = top_corner_r);

        // Upper-right rounded corner
        translate([
             plate_w / 2 - top_corner_r,
             plate_d / 2 - top_corner_r
        ])
            circle(r = top_corner_r);
    }
}

// ============================================================
// HOLE CUTTERS
// ============================================================

module all_hole_cuts() {
    for (p = hole_positions) {
        translate([
            p[0],
            p[1],
            -0.1
        ])
            cylinder(
                h = plate_t + 0.2,
                d = final_hole_d
            );
    }
}

// ============================================================
// PRINTED PART
// ============================================================

module battery_controller_holder() {
    difference() {

        linear_extrude(height = plate_t)
            controller_plate_profile_2d();

        all_hole_cuts();
    }
}

// ============================================================
// PREVIEW-ONLY REFERENCES
// ============================================================

module bottom_cover_edge_reference() {
    %color("DodgerBlue", 0.45)
        translate([
            -plate_w / 2,
            -plate_d / 2 - 0.5,
            0
        ])
            cube([
                plate_w,
                0.35,
                plate_t
            ]);
}

module hole_reference_posts() {
    for (p = hole_positions) {
        %color("Crimson", 0.50)
            translate([
                p[0],
                p[1],
                plate_t
            ])
                cylinder(
                    h = 2,
                    d = final_hole_d
                );
    }
}

// ============================================================
// OUTPUT
// ============================================================

battery_controller_holder();

if (show_bottom_cover_edge_reference)
    bottom_cover_edge_reference();

if (show_hole_reference_posts)
    hole_reference_posts();

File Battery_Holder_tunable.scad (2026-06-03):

// ============================================================
// Battery_Holder_tunable.scad
// Generated by Battery Holder Designer
//
// The battery and screw hardware are reference geometry only.
// They appear in preview when enabled but are not exported.
// ============================================================

$fn = 96;

// ---------------- HOLDER ----------------
overall_w = 61.2827;
overall_d = 64.1609;
overall_h = 5.9252;

floor_t = 0.44385;
wall_h = 5.18313;
flange_t = 0.765216;
tray_wall_t = 1;
flange_z = overall_h - flange_t;

// ---------------- BATTERY / POCKET ----------------
battery_w = 48;
battery_d = 57;
battery_h = 5;
clearance_x = 0.5;
clearance_y = 0.5;
battery_offset_x = 0;
battery_offset_y = 0;

pocket_w = battery_w + clearance_x * 2;
pocket_d = battery_d + clearance_y * 2;
pocket_x0 = battery_offset_x - pocket_w / 2;
pocket_y0 = battery_offset_y - pocket_d / 2;

// ---------------- SCREW PATTERN ----------------
hole_pitch_x = 58;
hole_pitch_y = 49;
hole_d = 2.41639;
underside_hardware_d = 5.4;
hardware_reference_h = 6;

hole_x = hole_pitch_x / 2;
hole_y = hole_pitch_y / 2;
hole_positions = [
    [-hole_x, -hole_y],
    [ hole_x, -hole_y],
    [-hole_x,  hole_y],
    [ hole_x,  hole_y]
];

// ---------------- OPENINGS ----------------
// Rear opening is cut in from +Y edge and through the rear tray wall.
rear_notch_w = 9.17705;
rear_notch_x = -15.5;
rear_notch_extra_into_pocket = 1.25;

// Side opening is cut in from -X edge and through the left tray wall.
side_notch_d = 11.9299;
side_notch_y = -10.5;
side_notch_extra_into_pocket = 1.25;

// ---------------- PREVIEW REFERENCES ----------------
show_battery_reference = true;
show_hardware_references = true;
show_original_stl = false;
original_stl_path = "";
stl_scale = 1000;
stl_translate = [0, 0, 0];
stl_rotate = [0, 0, 0];

// ============================================================
// CUTTERS
// ============================================================

module mounting_hole(x, y) {
    translate([x, y, flange_z - 0.1])
        cylinder(h = flange_t + 0.3, d = hole_d);
}

module rear_notch_cut(z_start = floor_t, cut_h = overall_h + 1) {
    translate([
        rear_notch_x - rear_notch_w / 2,
        pocket_y0 + pocket_d - tray_wall_t - 0.01,
        z_start
    ])
        cube([
            rear_notch_w,
            overall_d / 2 - (pocket_y0 + pocket_d)
                + tray_wall_t + rear_notch_extra_into_pocket + 0.02,
            cut_h
        ]);
}

module side_notch_cut(z_start = floor_t, cut_h = overall_h + 1) {
    translate([
        -overall_w / 2 - 0.01,
        side_notch_y - side_notch_d / 2,
        z_start
    ])
        cube([
            pocket_x0 - (-overall_w / 2)
                + tray_wall_t + side_notch_extra_into_pocket + 0.02,
            side_notch_d,
            cut_h
        ]);
}

// ============================================================
// HOLDER GEOMETRY
// ============================================================

module battery_floor() {
    translate([pocket_x0, pocket_y0, 0])
        cube([pocket_w, pocket_d, floor_t]);
}

module tray_walls_uncut() {
    difference() {
        translate([
            pocket_x0 - tray_wall_t,
            pocket_y0 - tray_wall_t,
            0
        ])
            cube([
                pocket_w + tray_wall_t * 2,
                pocket_d + tray_wall_t * 2,
                wall_h
            ]);

        translate([pocket_x0, pocket_y0, floor_t])
            cube([pocket_w, pocket_d, wall_h + 1]);
    }
}

module tray_walls() {
    difference() {
        tray_walls_uncut();

        // BOTH openings cut through the supporting vertical tray walls.
        rear_notch_cut();
        side_notch_cut();
    }
}

module top_flange() {
    difference() {
        translate([-overall_w/2, -overall_d/2, flange_z])
            cube([overall_w, overall_d, flange_t]);

        translate([pocket_x0, pocket_y0, flange_z - 0.1])
            cube([pocket_w, pocket_d, flange_t + 0.3]);

        // BOTH openings cut through the top flange.
        rear_notch_cut(flange_z - 0.1, flange_t + 0.3);
        side_notch_cut(flange_z - 0.1, flange_t + 0.3);

        for (pos = hole_positions)
            mounting_hole(pos[0], pos[1]);
    }
}

module battery_holder() {
    union() {
        battery_floor();
        tray_walls();
        top_flange();
    }
}

// ============================================================
// PREVIEW-ONLY REFERENCE GEOMETRY
// ============================================================

module battery_reference() {
    %color("DodgerBlue", 0.35)
        translate([
            battery_offset_x - battery_w/2,
            battery_offset_y - battery_d/2,
            floor_t
        ])
            cube([battery_w, battery_d, battery_h]);
}

module hardware_references() {
    for (pos = hole_positions) {
        %color("Crimson", 0.45)
            translate([pos[0], pos[1], flange_z - hardware_reference_h])
                cylinder(h = hardware_reference_h, d = underside_hardware_d);
    }
}

module original_stl_reference() {
    if (original_stl_path != "")
        %color("LimeGreen", 0.22)
            translate(stl_translate)
                rotate(stl_rotate)
                    scale([stl_scale, stl_scale, stl_scale])
                        import(original_stl_path, convexity = 10);
}

// ============================================================
// OUTPUT
// ============================================================

battery_holder();

if (show_battery_reference)
    battery_reference();

if (show_hardware_references)
    hardware_references();

if (show_original_stl)
    original_stl_reference();

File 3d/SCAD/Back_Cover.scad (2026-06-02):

// ============================================================
// Back_Cover.scad
// Rebuilt from Back_Cover.stl and measured screenshots
//
// Orientation:
//   X = width
//   Y = length
//   Z = thickness / boss depth
//
// The outside finished face is on top.
// The internal screw bosses extend downward.
// Units: mm
// ============================================================

$fn = 96;

// ============================================================
// MAIN PANEL DIMENSIONS
// ============================================================

plate_x = 76.9374;
plate_y = 166.1777;

// Extracted from STL:
// upper outside surface to underside flat surface
plate_h = 3.2828;

// Rounded corners estimated from STL outer contour
corner_r = 6.0;

// Small perimeter bevel / flare visible on the outside edge
edge_bevel = 0.13;
edge_bevel_h = 0.18;

// ============================================================
// LARGE CAMERA / BUMP OPENING
// ============================================================

camera_hole_d = 15.1144;

// Position relative to center of back plate.
// Negative Y = camera-hole end of the cover.
camera_x = -0.2718;
camera_y = -61.4483;

// ============================================================
// SCREW HOLE / BOSS DIMENSIONS
// ============================================================

// Visible circular recess on finished outside face
counterbore_d = 9.2351;
counterbore_depth = 1.89245;

// Small through-hole inside each recess/boss
screw_hole_d = 2.58313;

// Underside boss outer diameter
boss_d = 6.52951;

// Four shorter bosses
short_boss_h = 3.51307;

// Two taller bosses farthest away from the camera opening
tall_boss_h = 8.33461;

// ============================================================
// BOSS / HOLE POSITIONS
// Extracted from STL cross-sections, centered on the plate.
// Layout shown with camera end at negative Y.
//
//     TL                 TR        <- tall bosses
//
//     ML                 MR        <- short bosses
//
//     BL                 BR        <- short bosses
//
//             CAMERA
// ============================================================

boss_positions = [
    // x,        y,        boss height
    [-22.8128,  55.6865, tall_boss_h],   // top left
    [ 25.8846,  55.5952, tall_boss_h],   // top right

    [-24.5100,  21.0340, short_boss_h],  // middle left
    [ 24.5291,  21.0340, short_boss_h],  // middle right

    [-24.6543, -37.0091, short_boss_h],  // lower left
    [ 24.5291, -37.0091, short_boss_h]   // lower right
];

// ============================================================
// HELPERS
// ============================================================

module rounded_rect(w, h, r) {
    hull() {
        translate([ w/2-r,  h/2-r]) circle(r = r);
        translate([-w/2+r,  h/2-r]) circle(r = r);
        translate([ w/2-r, -h/2+r]) circle(r = r);
        translate([-w/2+r, -h/2+r]) circle(r = r);
    }
}

// ============================================================
// MAIN ROUNDED BACK PANEL
// Slightly beveled around the outside edge.
// Bottom/internal side is at Z = 0.
// Outside finished surface is at Z = plate_h.
// ============================================================

module beveled_panel_blank() {
    hull() {
        // Slightly inset underside edge
        translate([0, 0, 0])
            linear_extrude(height = edge_bevel_h)
                rounded_rect(
                    plate_x - edge_bevel * 2,
                    plate_y - edge_bevel * 2,
                    corner_r - edge_bevel
                );

        // Full-size upper/outside surface
        translate([0, 0, edge_bevel_h])
            linear_extrude(height = plate_h - edge_bevel_h)
                rounded_rect(
                    plate_x,
                    plate_y,
                    corner_r
                );
    }
}

// ============================================================
// HOLES THROUGH THE PANEL
// ============================================================

module camera_opening() {
    translate([camera_x, camera_y, -1])
        cylinder(
            h = plate_h + 2,
            d = camera_hole_d
        );
}

module screw_counterbore_cut(x, y) {
    // Small through-hole
    translate([x, y, -1])
        cylinder(
            h = plate_h + 2,
            d = screw_hole_d
        );

    // Wide recessed pocket on the outside face
    translate([x, y, plate_h - counterbore_depth])
        cylinder(
            h = counterbore_depth + 1,
            d = counterbore_d
        );
}

module all_panel_holes() {
    camera_opening();

    for (p = boss_positions) {
        screw_counterbore_cut(p[0], p[1]);
    }
}

// ============================================================
// UNDERSIDE SCREW BOSSES
// Bosses extend downward from the inside face of the panel.
// ============================================================

module one_boss(x, y, h) {
    difference() {
        translate([x, y, -h])
            cylinder(
                h = h,
                d = boss_d
            );

        translate([x, y, -h - 1])
            cylinder(
                h = h + 2,
                d = screw_hole_d
            );
    }
}

module all_bosses() {
    for (p = boss_positions) {
        one_boss(p[0], p[1], p[2]);
    }
}

// ============================================================
// FINAL BACK COVER
// ============================================================

module back_cover() {
    union() {
        difference() {
            beveled_panel_blank();
            all_panel_holes();
        }

        all_bosses();
    }
}

back_cover();

// ============================================================
// OPTIONAL VIEWS / STL OVERLAY
// ============================================================

// To inspect the internal boss side facing upward, replace:
//
//     back_cover();
//
// with:
//
//     rotate([180, 0, 0]) back_cover();
//
//
// To compare against your original STL, place Back_Cover.stl
// beside this file and uncomment below. The original STL was
// exported in meter-scale coordinates, so it is scaled by 1000.
//
// %translate([18.1105, -40.0639, -56.2831])
//     scale([1000, 1000, 1000])
//         import("Back_Cover.stl", convexity = 10);

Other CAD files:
3d/heat_sim_cases/heat_sim_full_sfepy/meshes/main_case.stl
3d/heat_sim_cases/heat_sim_full_sfepy/meshes/part6_3mm_004.stl
3d/heat_sim_cases/heat_sim_full_sfepy/meshes/battery_holder.stl
3d/STL/Battery_Controller_Holder.stl
3d/SCAD/Battery_holder.scad
3d/SCAD/Bottom_cover.scad
3d/SCAD/Camera_bump.scad
3d/SCAD/Case_assembly.scad
3d/SCAD/Components.scad
3d/SCAD/Compute_module_holder.scad
3d/SCAD/Full_assembly.scad
3d/SCAD/TypeC_Entrance.scad
3d/SCAD/main_case.scad
3d/STL/Back_Cover_Camera_Bump.stl
3d/STL/Battery_Holder.stl
3d/STL/Bottom_Cover.stl
3d/heat_sim_cases/heat_sim_full_sfepy/meshes/back_cover.stl
3d/heat_sim_cases/heat_sim_full_sfepy/meshes/back_cover_camera_bump.stl
3d/heat_sim_cases/heat_sim_full_sfepy/meshes/baseboard.stl
3d/heat_sim_cases/heat_sim_full_sfepy/meshes/battery.stl
3d/heat_sim_cases/heat_sim_full_sfepy/meshes/bottom_cover.stl
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

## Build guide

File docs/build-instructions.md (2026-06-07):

## CM4 Deferred Build

Use the deferred CM4 flow from Linux or WSL:

```sh
bash os/build.sh list-devices
bash os/build.sh deferred --device /dev/sdX
```

During an interactive build, the script asks for:

- Wi-Fi country, default `US`
- optional Wi-Fi SSID
- optional Wi-Fi password

If you need to push updated overlay files onto an already-flashed card without reflashing the base image:

```sh
sh os/reapply-overlay.sh /dev/sdX
```

## First Boot Notes

On first boot, the device autologins root on `tty1` and runs `firstboot-install.sh`.

- If network is not ready, the script waits indefinitely and prompts on `tty1`.
- If package install fails, the script drops into an interactive recovery shell on `tty1`.
- If you get dropped into that shell and the system otherwise looks ready, you may only need to type `reboot`.

Default seeded credentials:

- username: `unlim8ted`
- password: `unlim8ted`

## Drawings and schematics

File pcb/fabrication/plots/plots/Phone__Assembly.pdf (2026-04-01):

A

A

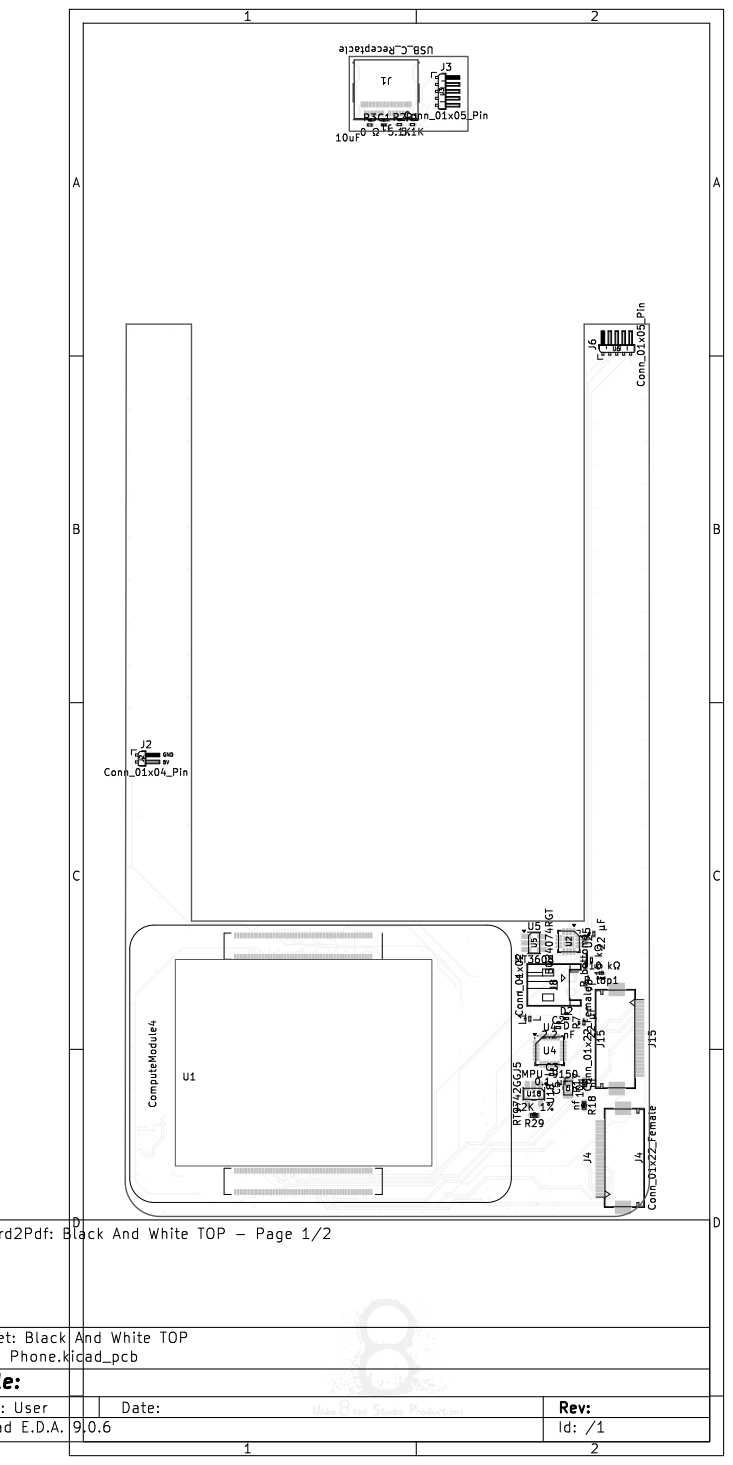
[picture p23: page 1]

Id: /1 Title: File: Phone.kicad_pcb Sheet: Black And White TOP

MK2 | U3 | J5 J7 | 1 | 2

A

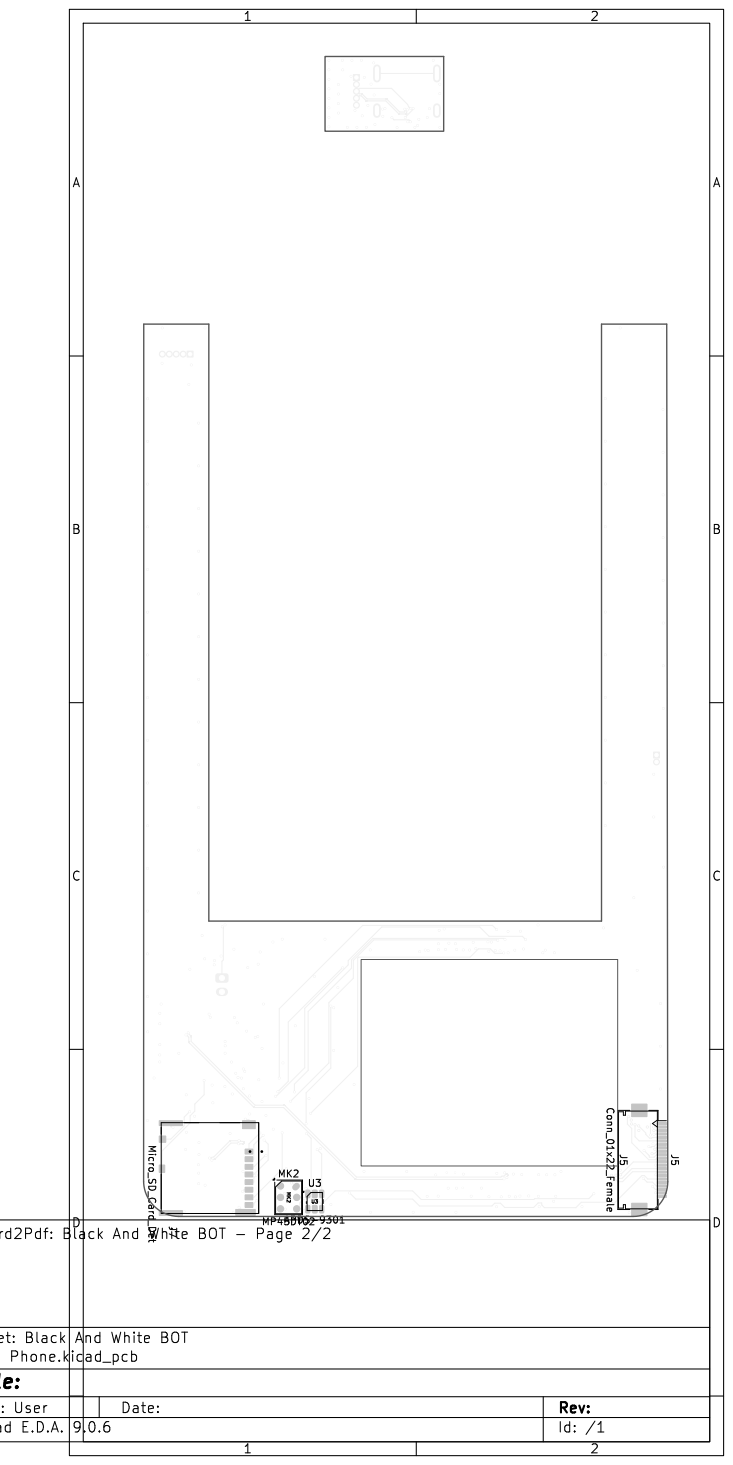
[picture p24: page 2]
D Date: KiCad; E.D.A. 9.0.6 Size: User; Rev:; Id: /1 Title: File: Phone.kicad_pcb Sheet: Black; And; White; BOT Board2Pdf:; Black; BOT -; Page 2/2; MP45DT02 MK2 APDS-9301; Conn_01x22_Female; J5 Micro_SD_Card_Det

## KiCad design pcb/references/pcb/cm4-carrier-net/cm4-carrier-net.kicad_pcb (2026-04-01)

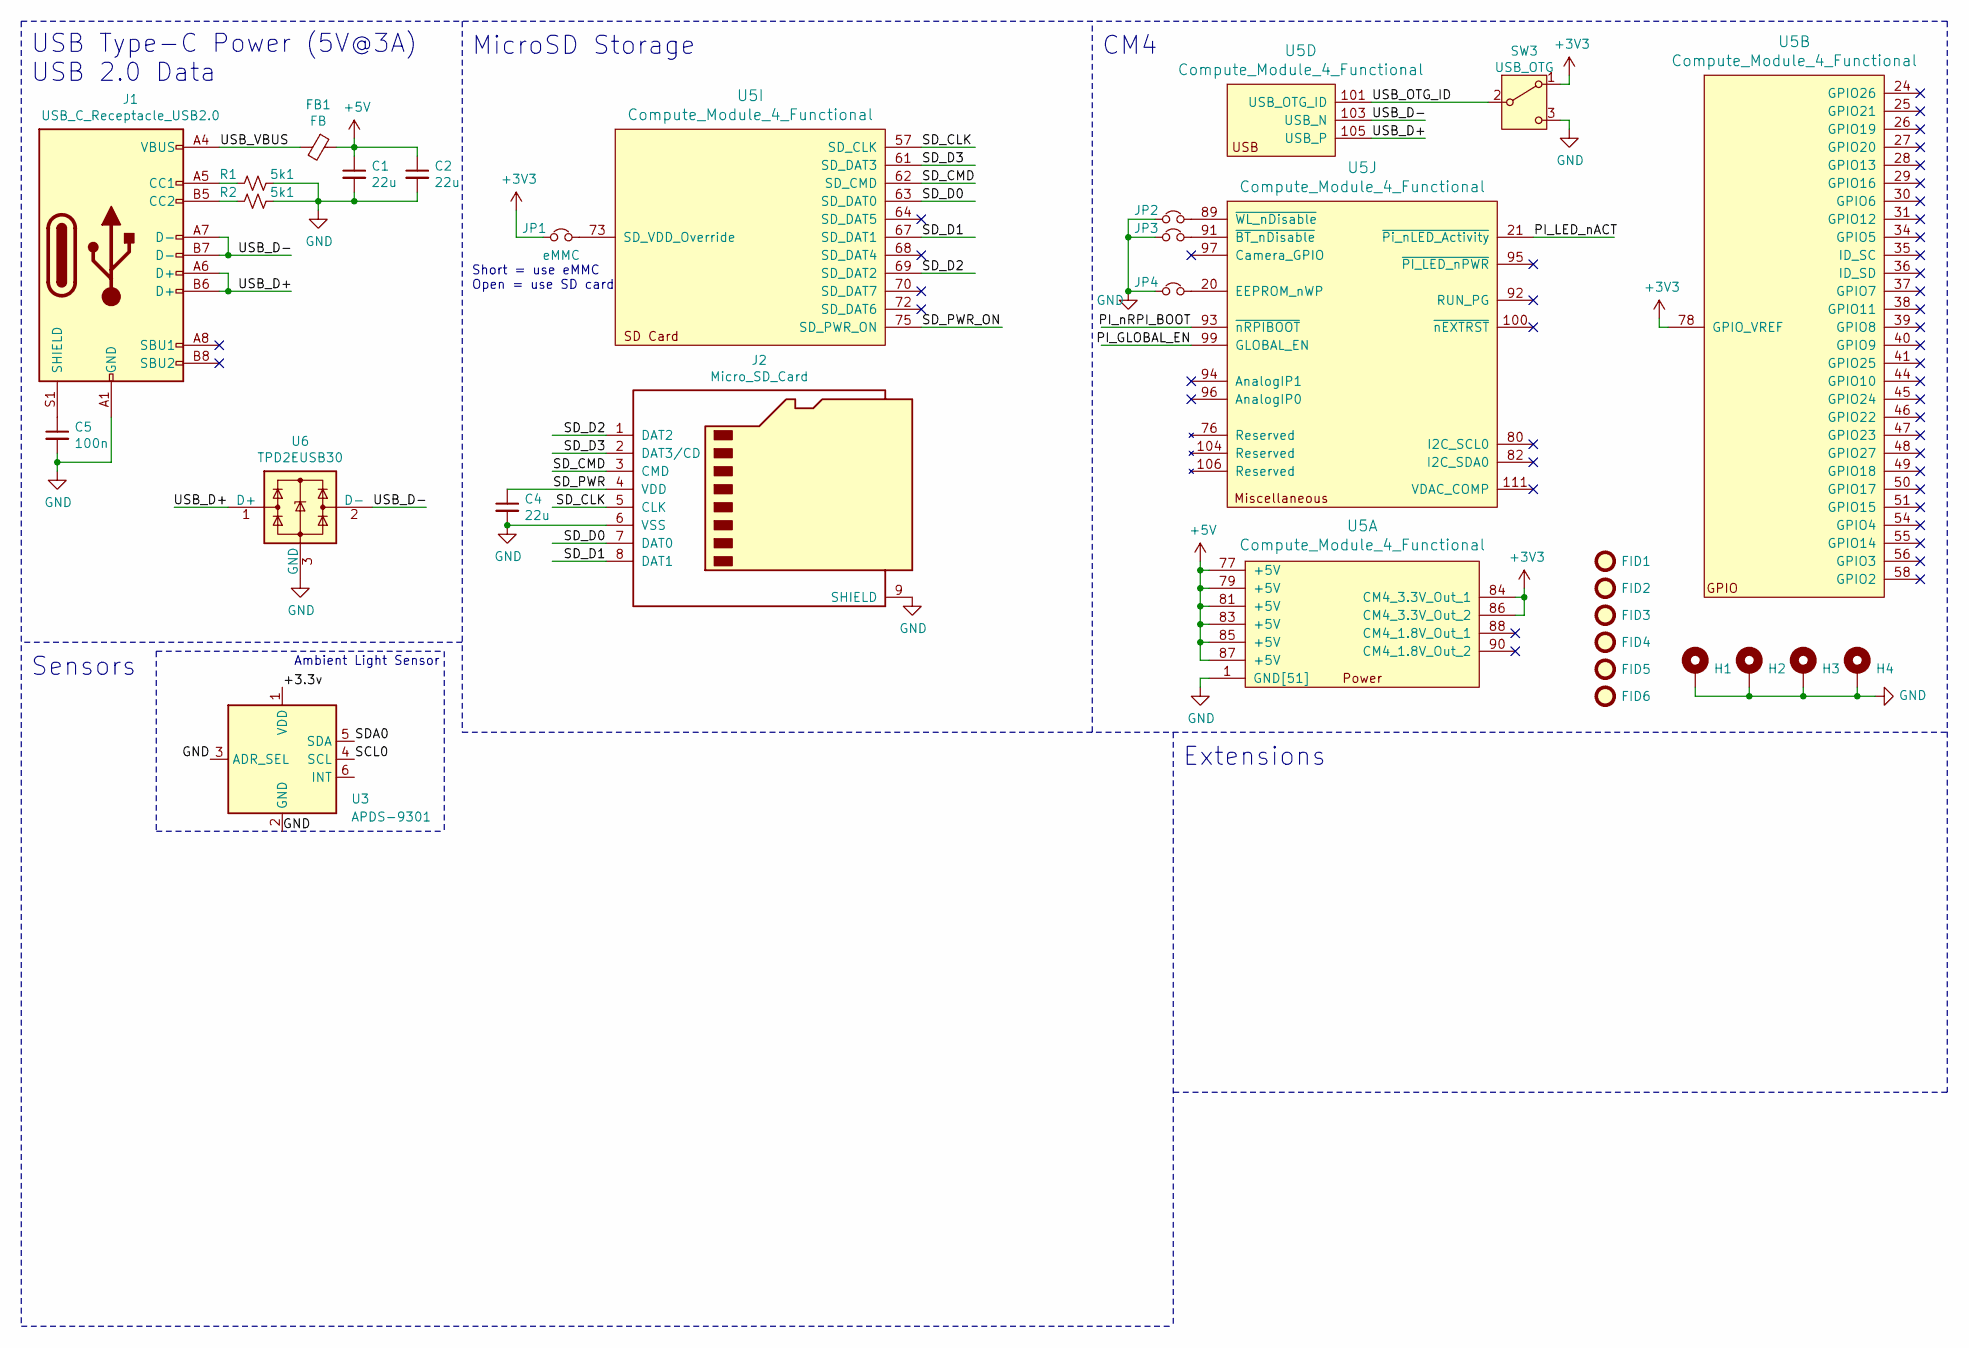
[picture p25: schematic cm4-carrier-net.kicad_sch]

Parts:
C1, C2, C4: 22u; C_0805_2012Metric
C5: 100n; C_0805_2012Metric
FB1: FB; L_0805_2012Metric
FID1, FID2, FID3, FID4, FID5, FID6: Fiducial; Fiducial_0.75mm_Mask1.5mm
H1, H2, H3, H4: MountingHole_Pad; MountingHole_2.7mm_M2.5_Pad_Via
J1: USB_C_Receptacle_USB2.0; USB_C_Receptacle_GCT-USB4105
J2: Micro_SD_Card; microSD_HC_Molex_104031-0811
JP1: eMMC; J_Small_NC
JP2: ~WL_nDisable; J_Small_NC
JP3: ~BT_nDisable; J_Small_NC
JP4: EEPROM_nWP; J_Small_NC
R1, R2: 5k1; R_0603_1608Metric
SW3: USB_OTG; SW_SPDT_CK-JS102011SAQN
U3: APDS-9301; Broadcom_APDS-9301
U5: Compute_Module_4_Functional; Raspberry-Pi-4-Compute-Module
U6: TPD2EUSB30; Texas_DRT-3

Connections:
+3V3: JP1.1, SW3.1 (A), U5.78 (GPIO_VREF), U5.84 (CM4_3.3V_Out_1), U5.86 (CM4_3.3V_Out_2)
+5V: C1.1, C2.1, FB1.1, U5.77 (+5V), U5.79 (+5V), U5.81 (+5V), U5.83 (+5V), U5.85 (+5V), U5.87 (+5V)
/+3.3v: U3.1 (VDD)
/PI_GLOBAL_EN: U5.99 (GLOBAL_EN)
/PI_LED_nACT: U5.21 (~Pi_nLED_Activity)
/PI_nRPI_BOOT: U5.93 (~nRPIBOOT)
/SCL0: U3.4 (SCL)
/SDA0: U3.5 (SDA)
/SD_CLK: J2.5 (CLK), U5.57 (SD_CLK)
/SD_CMD: J2.3 (CMD), U5.62 (SD_CMD)
/SD_D0: J2.7 (DAT0), U5.63 (SD_DAT0)
/SD_D1: J2.8 (DAT1), U5.67 (SD_DAT1)
/SD_D2: J2.1 (DAT2), U5.69 (SD_DAT2)
/SD_D3: J2.2 (DAT3/CD), U5.61 (SD_DAT3)
/SD_PWR: C4.1, J2.4 (VDD)
/SD_PWR_ON: U5.75 (SD_PWR_ON)
/USB_D+: J1.A6 (D+), J1.B6 (D+), U5.105 (USB_P), U6.1 (D+)
/USB_D-: J1.A7 (D-), J1.B7 (D-), U5.103 (USB_N), U6.2 (D-)
/USB_OTG_ID: SW3.2 (B), U5.101 (USB_OTG_ID)
/USB_VBUS: FB1.2, J1.A4 (VBUS), J1.A9 (VBUS), J1.B4 (VBUS), J1.B9 (VBUS)
GND: C1.2, C2.2, C4.2, C5.2, H1.1, H2.1, H3.1, H4.1, J1.A1 (GND), J1.A12 (GND), J1.B1 (GND), J1.B12 (GND), J2.6 (VSS), J2.9 (SHIELD), JP2.1, JP3.1, JP4.1, R1.1, R2.1, SW3.3 (C), U3.2 (GND), U3.3 (ADR_SEL), U5.1 (GND[51]), U5.2 (GND[51]), U5.7 (GND[51]), U5.8 (GND[51]), U5.13 (GND[51]), U5.14 (GND[51]), U5.22 (GND[51]), U5.23 (GND[51]), U5.32 (GND[51]), U5.33 (GND[51]), U5.42 (GND[51]), U5.43 (GND[51]), U5.52 (GND[51]), U5.53 (GND[51]), U5.59 (GND[51]), U5.60 (GND[51]), U5.65 (GND[51]), U5.66 (GND[51]), U5.71 (GND[51]), U5.74 (GND[51]), U5.98 (GND[51]), U5.107 (GND[51]), U5.108 (GND[51]), U5.113 (GND[51]), U5.114 (GND[51]), U5.119 (GND[51]), U5.120 (GND[51]), U5.125 (GND[51]), U5.126 (GND[51]), U5.131 (GND[51]), U5.132 (GND[51]), U5.137 (GND[51]), U5.138 (GND[51]), U5.144 (GND[51]), U5.150 (GND[51]), U5.155 (GND[51]), U5.156 (GND[51]), U5.161 (GND[51]), U5.162 (GND[51]), U5.167 (GND[51]), U5.168 (GND[51]), U5.173 (GND[51]), U5.174 (GND[51]), U5.179 (GND[51]), U5.180 (GND[51]), U5.185 (GND[51]), U5.186 (GND[51]), U5.191 (GND[51]), U5.192 (GND[51]), U5.197 (GND[51]), U5.198 (GND[51]), U6.3 (GND)
unnamed: J1.A5 (CC1), R1.2
unnamed: J1.B5 (CC2), R2.2
unnamed: C5.1, J1.S1 (SHIELD)
unnamed: JP1.2, U5.73 (SD_VDD_Override)
unnamed: JP4.2, U5.20 (EEPROM_nWP)
unnamed: JP3.2, U5.91 (~BT_nDisable)
unnamed: JP2.2, U5.89 (~WL_nDisable)

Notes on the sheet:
MicroSD Storage
USB Type-C Power (5V@3A) USB 2.0 Data
Sensors
Ambient Light Sensor
Extensions
CM4
Short = use eMMC Open = use SD card

Board: 4 copper layers, 27 parts (9 on the bottom side), 21 nets, no tracks yet.

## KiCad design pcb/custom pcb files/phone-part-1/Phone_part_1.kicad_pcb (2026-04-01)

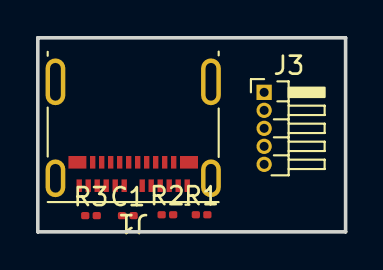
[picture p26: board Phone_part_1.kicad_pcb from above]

Board: 2 copper layers, 17.1 x 10.8 mm, 6 parts (0 on the bottom side), 7 nets, no tracks yet.

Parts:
C1: 10uF; C_0201_0603Metric
J1: USB_C_Receptacle; USB_C_Receptacle_Molex_105450-0101
J3: Conn_01x05_Pin; PinHeader_1x05_P1.00mm_Horizontal
R1, R2: 5.1K; R_0201_0603Metric
R3: 0 Ω; R_0201_0603Metric

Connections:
/+5v: C1.1, J1.A4 (VBUS), J1.A9 (VBUS), J1.B4 (VBUS), J1.B9 (VBUS), J3.1
/AIN0: J1.A5 (CC1), R1.1
/AIN1: J1.B5 (CC2), R2.1
/USB2_N: J1.A7 (D-), J1.B7 (D-), J3.3
/USB2_P: J1.A6 (D+), J1.B6 (D+), J3.4
GND: C1.2, J1.A1 (GND), J1.A12 (GND), J1.B1 (GND), J1.B12 (GND), J3.2, J3.5, R1.2, R2.2, R3.2
unnamed: J1.S1 (SHIELD), R3.1

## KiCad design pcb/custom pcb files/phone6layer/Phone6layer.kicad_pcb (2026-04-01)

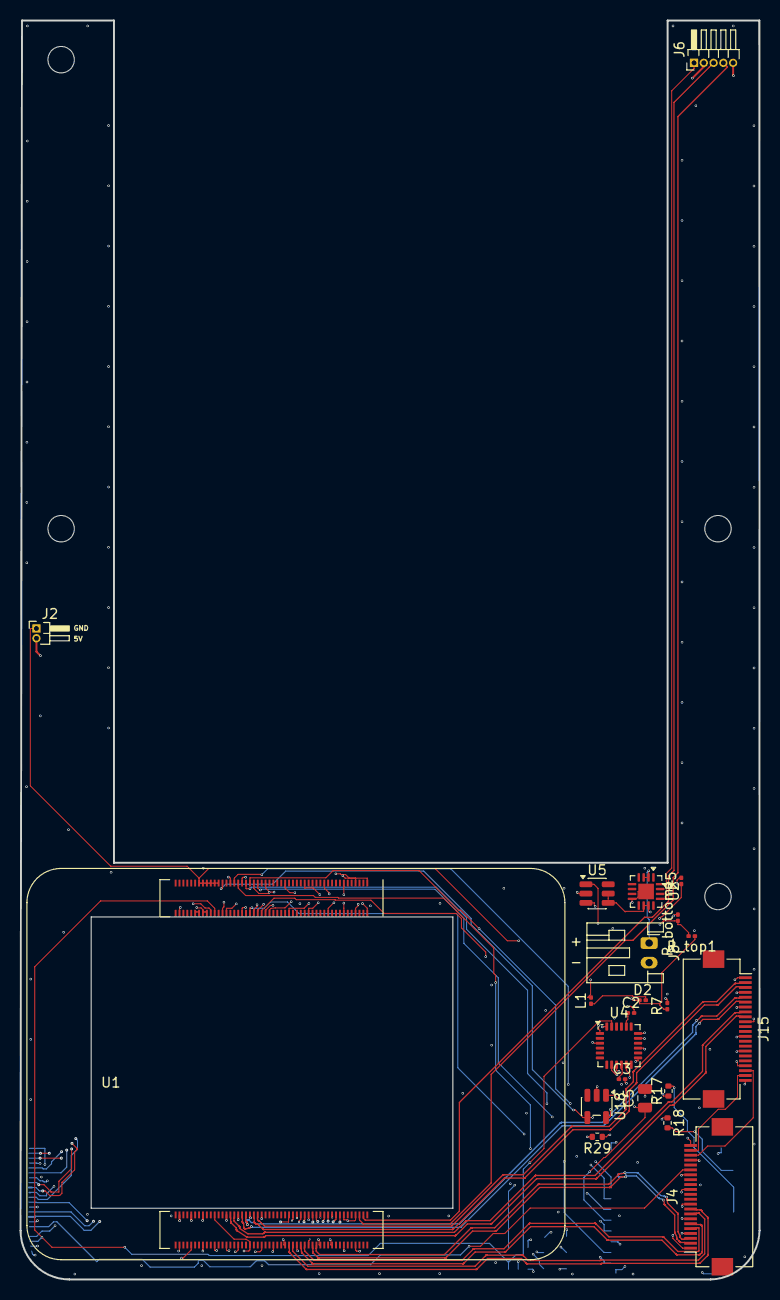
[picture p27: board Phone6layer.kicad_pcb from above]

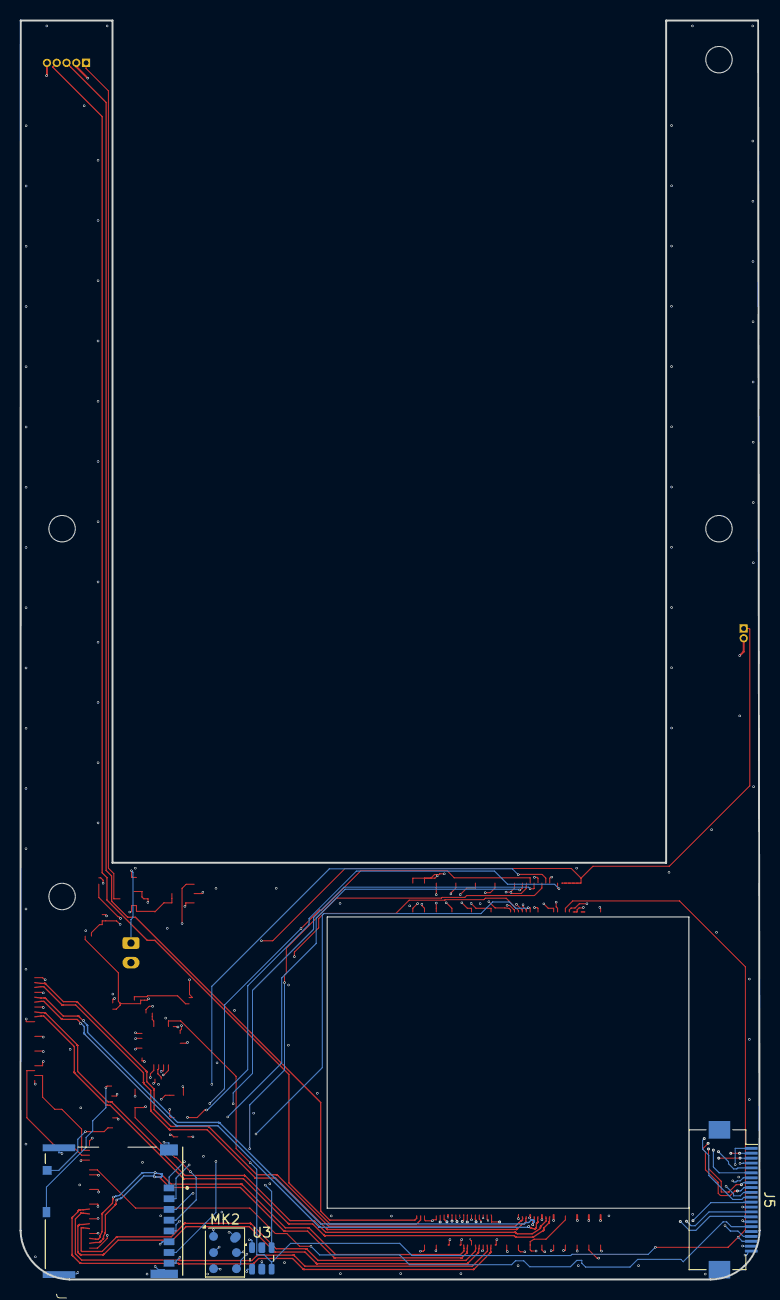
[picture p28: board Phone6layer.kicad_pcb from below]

Board: 6 copper layers, 75.5 x 128.7 mm, 26 parts (4 on the bottom side), 55 nets.

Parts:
C2: 2.2 nF; C_0201_0603Metric
C3: 0.1 µF; C_0201_0603Metric
C5: 10u; C_0805_2012Metric
D2: D; D_0201_0603Metric
J2: Conn_01x04_Pin; PinHeader_1x02_P1.00mm_Horizontal
J4, J5, J15: Conn_01x22_Female; Hirose_FH12-22S-0.5SH_1x22-1MP_P0.50mm_Horizontal
J6: Conn_01x05_Pin; PinHeader_1x05_P1.00mm_Horizontal
J7: Micro_SD_Card_Det; SDCARD_MOLEX_503398-1892
J8: Conn_01x02; JST_PH_S2B-PH-K_1x02_P2.00mm_Horizontal
L1: L; L_0201_0603Metric
MK2: MP45DT02; ST_HLGA-6_3.76x4.72mm_P1.65mm
R5, R7: 22 µF; R_0201_0603Metric
R17, R18: nf; R_0402_1005Metric
R29: 12K 1%; R_0402_1005Metric
R_bottom1: 15 kΩ; R_0201_0603Metric
R_top1: 110 kΩ; R_0201_0603Metric
U1: ComputeModule4; Raspberry-Pi-4-Compute-Module-Connector-Phone-Modified
U2: BQ24074RGT; VQFN-16-1EP_3x3mm_P0.5mm_EP1.6x1.6mm
U3: APDS-9301; Broadcom_APDS-9301
U4: MPU-9150; InvenSense_QFN-24_4x4mm_P0.5mm
U5: MT3608; SOT-23-6
U18: RT9742GGJ5; SOT-23-5

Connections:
/+1.8v: U1.88 (+1.8v_(Output)), U1.90 (+1.8v_(Output))
/+3.3v: J4.22, J5.22, J15.22, MK2.6 (VDD), R17.1, R29.1, U1.84 (+3.3v_(Output)), U1.86 (+3.3v_(Output)), U3.1 (VDD), U4.3 (VDD), U4.8 (VLOGIC), U4.13 (VDD), U18.5 (IN)
/+5v: D2.1 (K), J2.1, R7.1, R_top1.1, U1.77 (+5v_(Input)), U1.79 (+5v_(Input)), U1.81 (+5v_(Input)), U1.83 (+5v_(Input)), U1.85 (+5v_(Input)), U1.87 (+5v_(Input))
/CAM0_C_N: J4.8, U1.140 (CAM0_C_N)
/CAM0_C_P: J4.9, U1.142 (CAM0_C_P)
/CAM0_D0_N: J4.2, U1.128 (CAM0_D0_N)
/CAM0_D0_P: J4.3, U1.130 (CAM0_D0_P)
/CAM0_D1_N: J4.5, U1.134 (CAM0_D1_N)
/CAM0_D1_P: J4.6, U1.136 (CAM0_D1_P)
/CAM1_C_N: J5.8, U1.127 (CAM1_C_N)
/CAM1_C_P: J5.9, U1.129 (CAM1_C_P)
/CAM1_D0_N: J5.2, U1.115 (CAM1_D0_N)
/CAM1_D0_P: J5.3, U1.117 (CAM1_D0_P)
/CAM1_D1_N: J5.5, U1.121 (CAM1_D1_N)
/CAM1_D1_P: J5.6, U1.123 (CAM1_D1_P)
/CAM1_D2_N: J5.11, U1.133 (CAM1_D2_N)
/CAM1_D2_P: J5.12, U1.135 (CAM1_D2_P)
/CAM1_D3_N: J5.14, U1.139 (CAM1_D3_N)
/CAM1_D3_P: J5.15, U1.141 (CAM1_D3_P)
/CAM_GPIO: J4.17, J5.17
/DSI0_C_N: J15.8, U1.169 (DSI0_C_N)
/DSI0_C_P: J15.9, U1.171 (DSI0_C_P)
/DSI0_D0_N: J15.2, U1.157 (DSI0_D0_N)
/DSI0_D0_P: J15.3, U1.159 (DSI0_D0_P)
/DSI0_D1_N: J15.5, U1.163 (DSI0_D1_N)
/DSI0_D1_P: J15.6, U1.165 (DSI0_D1_P)
/PCM_CLK: MK2.4 (CLK), U1.54 (GPIO4)
/PCM_DIN: MK2.5 (DOUT), U1.58 (GPIO2)
/PCM_FS: MK2.2 (LR), U1.56 (GPIO3)
/Reserved: R18.1, U1.76 (Reserved)
/SCL0: J5.20, U1.80 (SCL0), U3.4 (SCL), U4.23 (SCL)
/SCL1: J4.20, J15.20
/SDA0: J5.21, U1.82 (SDA0), U3.5 (SDA), U4.24 (SDA)
/SDA1: J4.21, J15.21
/SD_CLK: J7.5 (CLK), U1.57 (SD_CLK)
/SD_CMD: J7.3 (CMD), U1.62 (SD_CMD)
/SD_DAT0: J7.7 (DAT0), U1.63 (SD_DAT0)
/SD_DAT1: J7.8 (DAT1), U1.67 (SD_DAT1)
/SD_DAT2: J7.1 (DAT2), U1.69 (SD_DAT2)
/SD_DAT3: J7.2 (DAT3/CD), U1.61 (SD_DAT3)
/SD_PWR: C5.1, J7.4 (VDD), U18.1 (OUT)
/SD_PWR_ON: R29.2, U1.75 (SD_PWR_ON), U18.4 (EN)
/USB2_N: J6.3, U1.103 (USB2_N)
/USB2_P: J6.4, U1.105 (USB2_P)
/VBUS_RAW: J6.1, U2.13 (IN)
GND: C2.2, C3.2, C5.2, J2.2, J4.1, J4.4, J4.7, J4.10, J4.13, J4.16, J4.19, J5.1, J5.4, J5.7, J5.10, J5.13, J5.16, J5.19, J6.2, J6.5, J7.6 (VSS), J7.11 (SHIELD), J8.2, J15.1, J15.4, J15.7, J15.10, J15.13, J15.16, J15.19, MK2.1 (GND), MK2.3 (GND), R5.2, R7.2, R_bottom1.2, U1.1 (GND), U1.2 (GND), U1.7 (GND), U1.8 (GND), U1.13 (GND), U1.14 (GND), U1.22 (GND), U1.23 (GND), U1.32 (GND), U1.33 (GND), U1.42 (GND), U1.43 (GND), U1.52 (GND), U1.53 (GND), U1.59 (GND), U1.60 (GND), U1.65 (GND), U1.66 (GND), U1.71 (GND), U1.74 (GND), U1.98 (GND), U1.107 (GND), U1.108 (GND), U1.113 (GND), U1.114 (GND), U1.119 (GND), U1.120 (GND), U1.125 (GND), U1.126 (GND), U1.131 (GND), U1.132 (GND), U1.137 (GND), U1.138 (GND), U1.144 (GND), U1.150 (GND), U1.155 (GND), U1.156 (GND), U1.161 (GND), U1.162 (GND), U1.167 (GND), U1.168 (GND), U1.173 (GND), U1.174 (GND), U1.179 (GND), U1.180 (GND), U1.185 (GND), U1.186 (GND), U1.191 (GND), U1.192 (GND), U1.197 (GND), U1.198 (GND), U2.8 (VSS), U2.17 (VSS), U3.2 (GND), U3.3 (ADR_SEL), U4.1 (CLKIN), U4.9 (AD0), U4.11 (FSYNC), U4.15 (GND), U4.17 (GND), U4.18 (GND), U5.2 (GND), U18.2 (GND)
unnamed: D2.2 (A), L1.1
unnamed: J7.10 (DET_A), R17.2
unnamed: J7.9 (DET_B), R18.2
unnamed: J8.1, U2.2 (BAT), U2.3 (BAT)
unnamed: C2.1, U4.20 (CPOUT)
unnamed: C3.1, U4.10 (REGOUT)
unnamed: R5.1, U2.10 (OUT), U2.11 (OUT), U5.4 (EN), U5.5 (IN)
unnamed: R_bottom1.1, R_top1.2, U5.3 (FB)
unnamed: L1.2, U5.1 (SW)

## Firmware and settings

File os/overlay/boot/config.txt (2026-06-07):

#[all]
#dtoverlay=vc4-kms-v3d
# dtoverlay=vc4-kms-dsi-waveshare-panel,6_25_inch

# Enable CSI explicitly for the CM4-NANO-C carrier. Adjust the overlay if the
# final module is not IMX219 on CAM0.
camera_auto_detect=0
dtoverlay=imx219,i2c_vc,cam0=on
auto_initramfs=1

# Force the USB controller into host mode so keyboards, mice, and other test
# peripherals enumerate reliably on the CM4 carrier.
dtoverlay=dwc2,dr_mode=host

# Reserve enough GPU memory for libcamera preview and chromium kiosk rendering.
gpu_mem=256

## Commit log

2026-04-01 Replace 1800mAh battery with 3000mAh in README
    Updated battery specifications and cost breakdown in README.
2026-04-01 add archived pcb assets
    [1578 500mAh battery.step, 1mmmeasurement.kicad_pcb, 1mmmeasurement.step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]
2026-04-08 add build scripts
    [config.txt, grub-live.cfg, grub-unlim8ted.cfg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]
2026-04-09 Revert "add build scripts"
    This reverts commit d89a7a2b70d2115c7ec0a0d4528cc6cb57167fb3.
    [config.txt, grub-live.cfg, grub-unlim8ted.cfg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]
2026-04-09 format build scripts and overlay better and simpler
    [config.txt]
2026-04-11 fix the CM4 root partition detection for Raspberry Pi OS image, add terminal app, and add default grow mb to build sh
2026-04-12 major changes to the build process and oss
    [config.txt]
2026-05-27 Added some 3d print case files
    [Battery_Controller_Holder.stl, Battery_Holder.stl, Main_Case.stl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]
2026-05-28 add bottom cover
    [Bottom_Cover.stl]
2026-05-28 fix type c port entrance size
    [Type_C_Port_Entrance.stl]
2026-05-28 more casing updates
    [Back_Cover.stl, Bottom_Cover.stl]
2026-05-29 updates to overlay
    [config.txt]
2026-05-30 casing updates
    [Back_Cover.stl, Back_Cover_Camera_Bump.stl]
2026-06-02 transition to scad and some other tools which kind of didn't work
    [Back_Cover.scad, Back_Cover.stl, Back_Cover_Camera_Bump.stl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]
2026-06-03 Updates to scad
    still working on battery holder
    [Back_Cover.scad, Battery_Holder_tunable.scad, Battery_holder.scad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]
2026-06-03 update an scad file
    [Battery_holder.scad]
2026-06-07 lots of work
    [Case_assembly.scad, Components.scad, Compute_module_holder.scad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]
2026-06-07 get the build script and first os boot working. Still broken DSI
    [config.txt]

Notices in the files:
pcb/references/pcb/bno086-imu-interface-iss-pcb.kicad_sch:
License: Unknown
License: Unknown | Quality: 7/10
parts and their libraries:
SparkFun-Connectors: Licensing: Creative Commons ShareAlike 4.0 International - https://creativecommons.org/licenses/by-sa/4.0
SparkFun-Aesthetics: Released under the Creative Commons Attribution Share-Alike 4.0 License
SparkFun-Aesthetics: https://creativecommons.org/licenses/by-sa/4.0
